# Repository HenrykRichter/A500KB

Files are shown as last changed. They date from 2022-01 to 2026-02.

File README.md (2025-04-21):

# A500KB
This project contains the material related to a custom Commodore Amiga Mechanical Keyboard. While the initial development target was the iconic Amiga 500, the keyboard also fits in A3000/A4000 (maybe also A2000) external keyboard enclosures. It features the ability to mount Mitsumi or Cherry switches. The Power, Drive and Caps-Lock LEDs are implemented as 7 individually configurable RGB LEDs. LED configuration is provided by an AmigaOS program that talks to the Keyboard over the regular connection. Headers for two additional low active input sources (e.g. HDD, Network) are also present.

The keyboard may be populated with two options of Switches and associated Keycaps. The first option are the tactile Mitsumi mechanical switches (E25-33-137) and original A2000/3000/4000 keycaps or A1200.net replica keycaps. Please note that the Mitsumi mechanical switches are quite rare. The second option for switches and keycaps is standard Cherry MX or compatibles. In that latter case, the keycaps for the original Amiga layout are hard to obtain. Recently, the user steveed on [Amibay](https://www.amibay.com/threads/amiga-mx-style-keycaps-pcbs.2446001/) has managed to get replica Amiga compatible keycaps ordered from SignaturePlastics. Consequently, the recent designs of the plate are targeted at Cherry MX compatible stabilizers. The PCB still accepts Mitsumi or Cherry MX (3 pin or 5 pin) compatible switches.

If building the full keyboard is not an option, a sub-project of A500KB might be of interest. The controller part of A500KB is also usable as standalone controller for classic Mitsumi keyboards (A500KB Mini). While that A500KB Mini approach won't give the benefit of mechanical switches, it'll offer the custom LED functionality of A500KB.

Please have a look at the README.md in PCB/ for ordering/building notes.

## Requirements

- Amiga 500 or A3000/A4000 keyboard case
- Main PCB and Switchplate PCB
- 96 Keyswitches (Mitsumi or Cherry)
- parts (including AT90USB1287, IS32FL3237, diodes, LEDs and passives)
- suitable LEDs need to be of ARGB type (analog, common anode) such as Würth 150141M173100, Brightek QBLP677-RGB or similar
- 3D Printed parts for LED light guides (transparent) and spacers

## Pictures

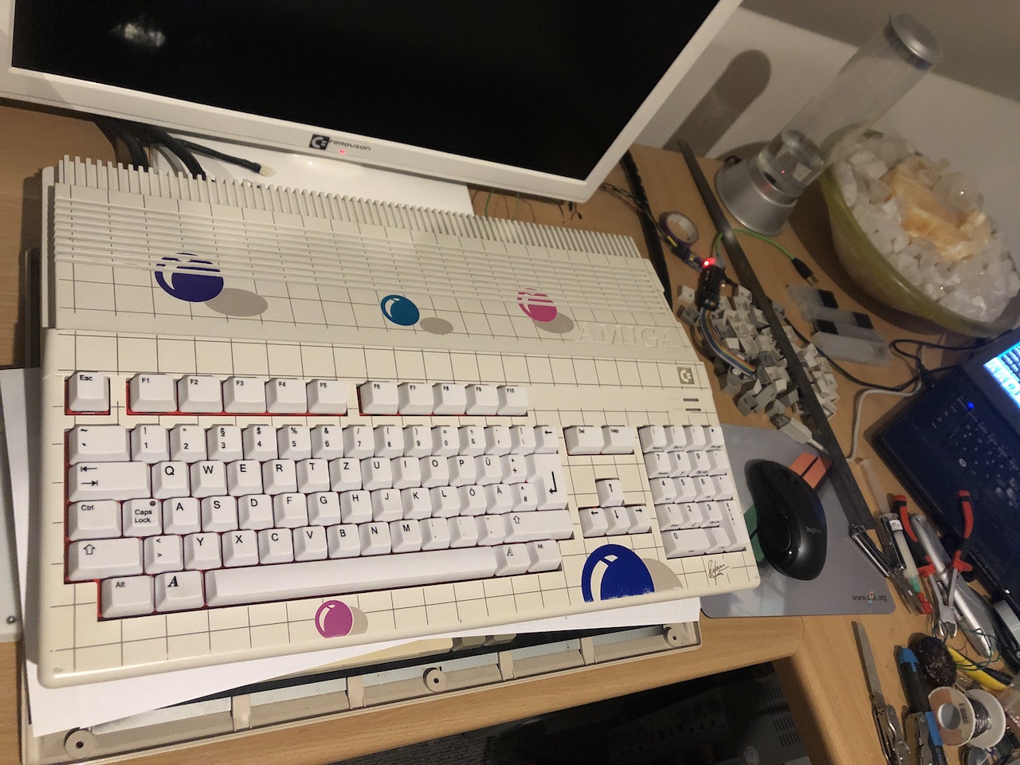
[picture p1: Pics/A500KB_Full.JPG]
front view


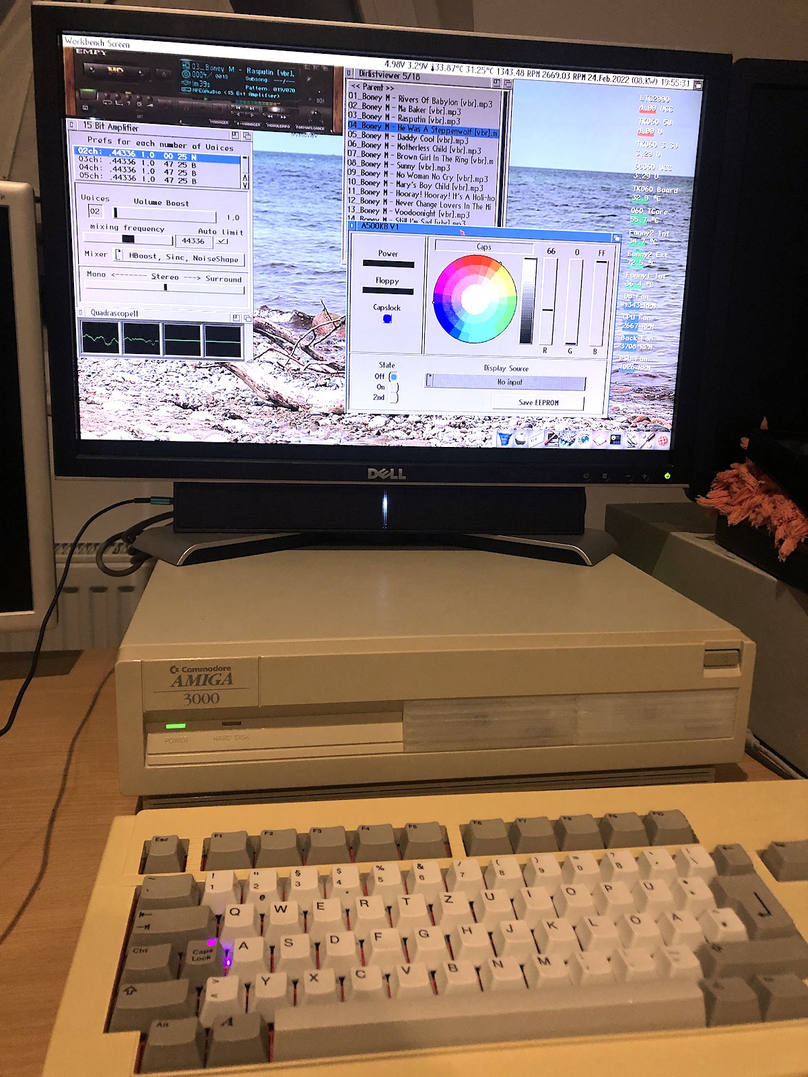
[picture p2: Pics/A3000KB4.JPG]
A3000


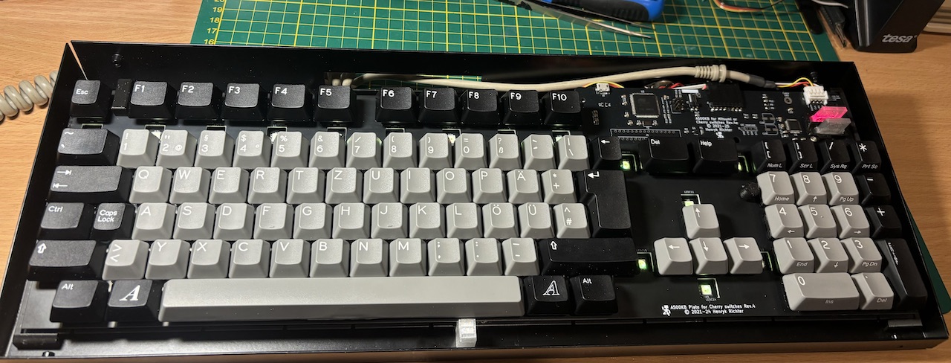
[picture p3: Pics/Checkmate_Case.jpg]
CheckmateCase


## Acknowledgements

Kicad 3D Models and original Footprints imported from:
https://github.com/perigoso/keyswitch-kicad-library

## History

Version 2 of the PCBs addresses several small issues with the prototype. Better fitment is provided for Costar style suports of the larger keys (Shift,Return,Space,Tab etc.). Also, those keys are rotated 90 degrees such that the wire of the supports gets better clearance. The plate PCB got positioning holes for the pins in the top cover of A3000/A4000 keyboards.  Some minor additions were done to the electronics, including larger Diodes and more pullup/down resistors. Version 4 (see below) addresses potential space issues with A500 cases and cabling headers.

A set of 3D printed parts to fit A500KB into the Checkmate external keyboard case has been added in Apr-2025. Please see [3DPrint](https://github.com/HenrykRichter/A500KB/tree/main/3DPrint/Checkmate_KB_Case) for STL files and guidance pictures.

## Caveats

Potential space issues in different styles of A500 cases affected early versions (up to V3) of the design, where the keyboard could only mounted with soldered cables in most A500 cases. Since V4e of the PCB design, the connector J4 has been moved so that it may be populated with an angled pin header and fit all A500 cases as well as external (A2000,A3000,A4000) cases.

## License
The PCB, it's design files and all support code (Amiga, Atmega) are licensed as [CC BY NC SA](https://creativecommons.org/licenses/by-nc-sa/4.0/deed.en).

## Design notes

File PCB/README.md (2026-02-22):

# A500KB Building Notes
This project contains the material related to a custom Commodore Amiga Mechanical Keyboard. While the initial development target was the iconic Amiga 500, the keyboard also fits in A3000/A4000 (maybe also A2000) external keyboard enclosures. It features the ability to mount Mitsumi or Cherry switches. The Power, Drive and Caps-Lock LEDs are implemented as 7 individually configurable RGB LEDs. LED configuration is provided by an AmigaOS program that talks to the Keyboard over the regular connection. Headers for two additional low active input sources (e.g. HDD, Network) are also present.

The two variants of the PCBs in this repository are discussed below. In a nutshell: order PCB and plate for the full keyboard or just the A500KBMini PCB for the standalone controller.

## A500KB (full)

### PCB ordering

**Caution** There are two styles of Keyboard and Plate designs. The one with the suffix "US" is designed specifically for large left Shift (2.75U) and the "BigAss" mirrored L style return key. Should your keycap set include an ISO-style return key (like in most of my pictures), please choose the variant without "US" suffix. See below for comparison pictures towards Keycap styles, if still unsure.

- 1 PCB from A500KB\_Gerber, 2 layer PCB in FR4, 1.2mm thickness for a little more space in bottom case (standard 1.6mm will still be compatible)
- 1 PCB from A500KBPlate\_Gerber, 1 layer PCB in FR4 or Alu, 1mm thickness for PCB or plate mounted MX stabilizers _OR_ A500KBPlate\_Gerber\_V2D.zip for Costar style stabilizers

Starting with V5, there is also a US version of PCB and Plate designs. The US variant includes a large LShift (2.75U) and a large Return (inverted L). Please note that the respective keycaps for ISO Keyboards will not fit on the US version and vice versa.

### 3D printing

The 3D printed parts are in the 3DPrint/ subfolder. Which of those files are to be printed depends on the target enclosure. Please note that bolts and nuts are required for mounting. 
The keyboard framing spacers are designed for countersunk M2.5 bolts with a total length of 5mm. 
The LED frame is to be mounted by flathead M2 bolts with a total length of 5mm and matching nuts.

As of A500KB V4, the 3D printed parts have been unified. The side spacers will fit A500 (and reproduction cases), as well as at least most of the external keyboard cases (tested: A2000,A3000,A4000 Mitsumi cases).

Four parts are designed for all keyboard types: 
- Keyboard\_Spacer\_L\_F2025  - left side of keyboard
- Keyboard\_Spacer\_R\_F2025  - right side of keyboard
- Keyboard\_Spacer\_VL\_F2025 - front left below spacebar
- Keyboard\_Spacer\_VR\_F2025 - front right below cursor keys

A500
- Keyboard\_LEDs\_Rahmen - frame for holding the LED lenses
- Keyboard\_LEDs - LED lenses to be printed (twice!) in transparent filament or resin. Keep infill low.

You also might consider to look at Spacebar\_ExtraSprings for Mitsumi mechanical based builds. This part allows to place additional springs under the space bar in the same way that was present with Mitsumi Amiga keyboards. 

Also of relevance for Mitsumi builds is Keyboard\_CapsLockLED to be printed in transparent filament or resin. This light guide is supposed to point towards the clear dot on the CapsLock key from underneath.

One CDTV Keyboard I came across had studs in its lower case which were about 2mm shorter than those of other 
A2000-4000 keyboards I encountered. The A500KB might sit a bit too low in such CDTV keyboard enclosures. Simply place
three 3D printed adapters of CDTVKeyboard\_Stud\_Adapter.stl on the top row studs in that case.

### Parts

- Please see schematics and/or A500KB.csv for the latest list. All needed components were marked active at the last check with common distributors (like Digikey or Mouser).
- The 7 RGB LEDs need to be of RGBA type (i.e. common Anode) and can be mounted as PLCC or with leads.
- Choose between D1 and D69, depending on switches and keycaps. For CherryMX switches (with SMD LED provision), D69 would be a good choice. D1 is better suited for Mitsumi switches and associated keycaps.
- C15/C16 are not needed.
- The 1x31 flat cable connector (J1) is not needed and stays unpopulated
- Screw-In PCB mounted stabilizers are recommended for Cherry MX and compatible
- see below for a description in which cases R6/R10/R11 need to be installed
- an iBOM is provided as PCB/bom/ibom.html as soldering aid. Please download before use.

### Building

- Solder the SMD components first. 
- Populate either D1 or D69 for CapsLock LED, not both. D2 as classic CapsLock LED is optional. D2 can also be disabled in firmware, if desired (i.e. populate R10 to disable D2).
- Install R6 with 390R for use of RGB LEDs at the positions of Power LED and Floppy LED. Leave R6 open when placing classic Commodore A500 Green/Orange or Red/Green LEDs.
- V3b/V4: install R11 when digital LEDs (SK9822 or APA102) are mounted to D70-D84. Leave R11 open, otherwise

After placing the SMD components, flash the ATMega firmware and verify that the keyboard PCB works.
- Option A) connect by USB to some PC and shorten the pins of the individual keys
- Option B) add A500 cable to J4 and test with AmigaTestKit or similar

Please note that diode reworking after the plate was placed and keyswitches were soldered is not a job I'd look forward to. Therefore, diode soldering and orientation should be verified before going further (!)

For CherryMX based builds, place the PCB mounted stabilizers including their wires in the next step. Screw-In type stabilizers should be preferred. 8U stabilizer wires are not commonly available. Hence, it might be necessary to custom-bend the spacebar wire (133.4mm wide, 1.5-1.6mm diameter).

Afterwards, the keyswitches may be added. It is suggested to place four keyswitches in the corners and one in the middle at first. This tends to help aligning the plate over the main PCB. 

Add the 3D printed spacers, LED frame and lenses.

Consider some electric short protection as the last step after fitment tests are done and possibly remaining THT parts (like J5) are in. For me, two layers of Kapton (or generic Polyimide) tape have been working well. The Kapton doesn't add significant thickness to the main PCB.

### PCB / Plate variant choice

The following pictures should help to decide which PCB and Plate variant to obtain. The critical part in this choice is the Return key, where the mounting points differ significantly between the international version (ISO) version and the US (ANSI) layout.
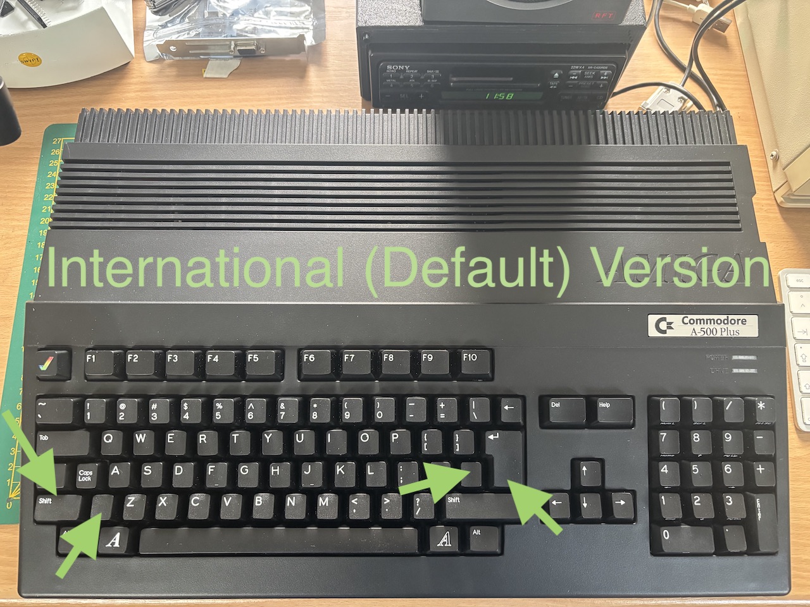
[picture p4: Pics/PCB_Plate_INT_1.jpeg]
INTL

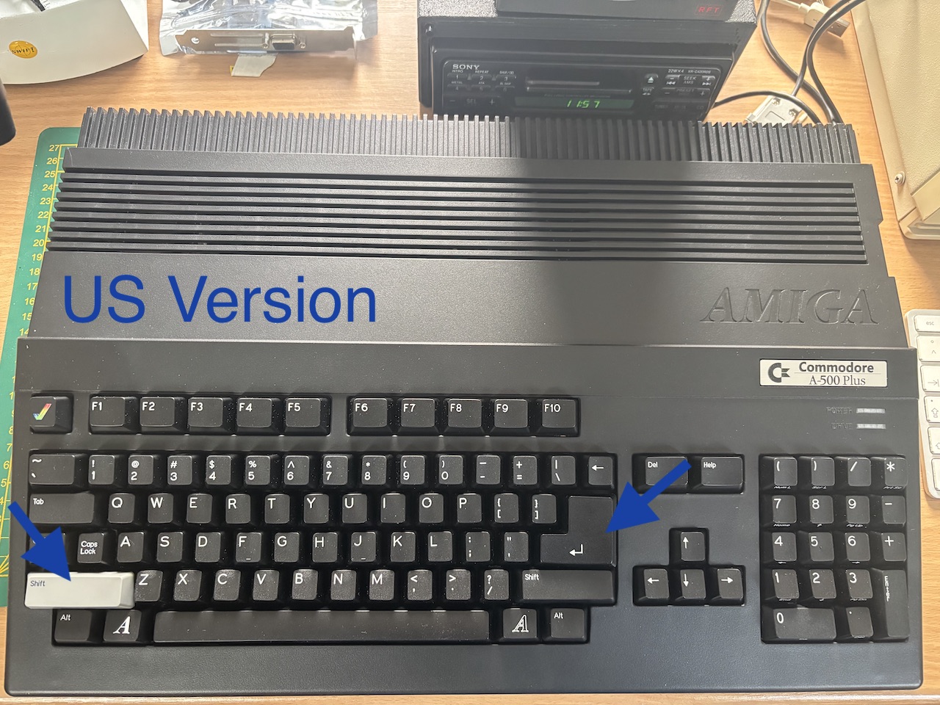
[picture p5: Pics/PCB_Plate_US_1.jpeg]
US1

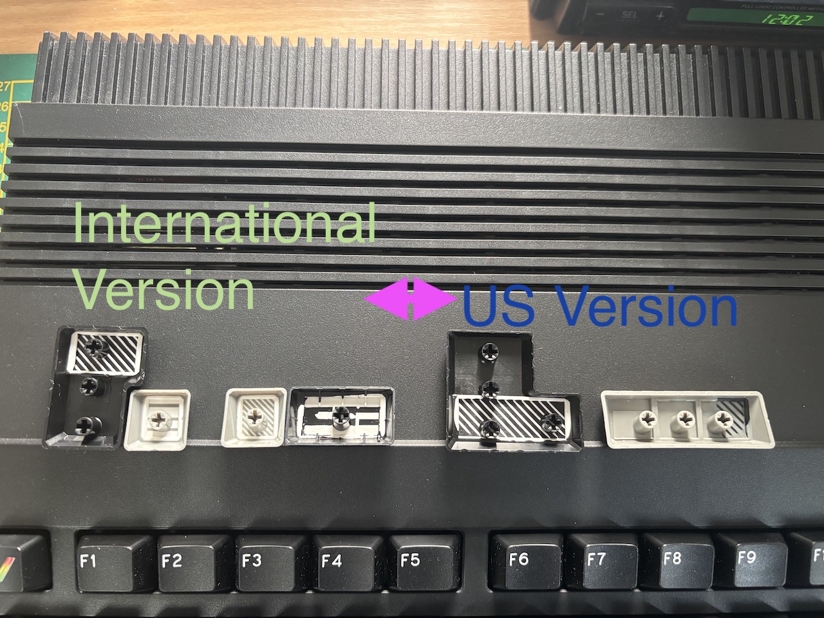
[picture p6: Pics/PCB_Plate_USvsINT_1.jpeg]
CMP1

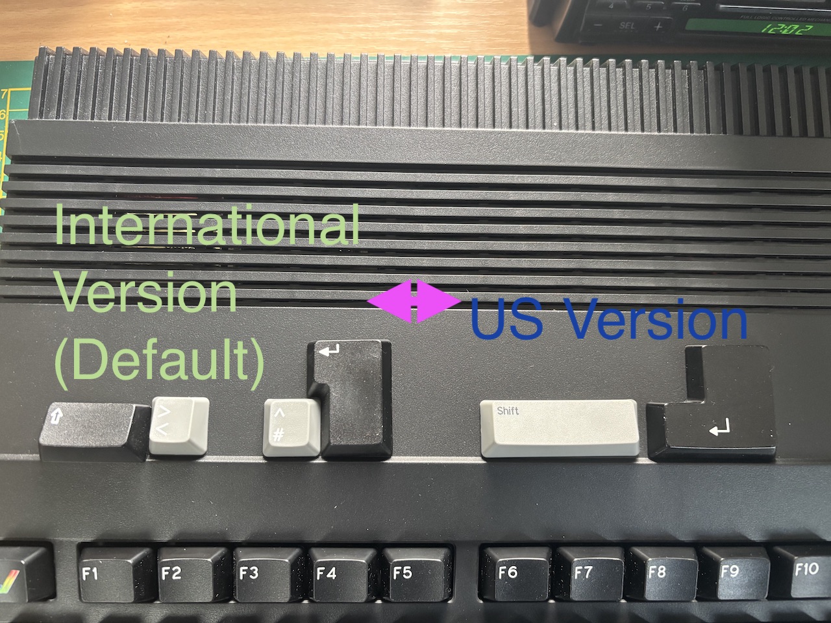
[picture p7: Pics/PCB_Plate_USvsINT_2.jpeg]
CMP2


## A500KBMini

A500KBMini is a little less demanding in the build procedure. There is, however a showstopper for prospective builds. None of the shops I am aware of carries the 1x31 angled FFC connector to be required for A500 Mitsumi Keyboards. Scavenging from broken Mitsumi keyboards might be an option.

### PCB ordering

- 1 PCB from A500KBMini\_Gerber, 2 layer PCB in FR4, 1mm-1.6mm thickness 

### 3D Printing
- Keyboard\_LEDs\_Rahmen as frame for holding the LED lenses
- Keyboard\_LEDs LED lenses to be printed (twice!) in transparent filament or resin

### Parts

- Please see schematics and/or A500KB.csv for the latest list. Exclude the 58 Diodes used for NKRO on the full keyboard. Except from the FFC connector, all other needed components were marked active at the last check with common distributors (like Digikey or Mouser).
- The 6 RGB LEDs need to be of RGBA type (i.e. common anode) and can be mounted as PLCC or with leads.
- C15/C16 are not needed.
- The 1x31 flat cable connector (J1) needs to be obtained and fitted.
- R10/R11 stay unpopulated

### Building

- Solder the SMD components first. 
- Install R6 with 390R for use of RGB LEDs at the positions of Power LED and Floppy LED. Leave R6 open when placing classic A500 Green/Orange or Red/Green LEDs.

After placing the SMD components, flash the ATMega firmware and verify that the keyboard PCB works.

Add the 3D printed LED frame and lenses.

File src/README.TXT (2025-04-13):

-------------------------------------------------------------------------------
- Amiga keyboard controller                                                   -
- author: Henryk Richter <henryk.richter@gmx.net>                             -
-------------------------------------------------------------------------------

This is the AT90USB program for a custom Amiga keyboard I was building. The
keyboard matrix matches the Mitsumi layout. It is active low. Therefore, the 
6 outputs are on by default and pulled down one-by-one in the scanning process. 

Since V4 of the firmware, the USB port has been enabled in device mode. 
CAUTION: USE ONLY ONE CONNECTION, EITHER USB OR AMIGA. NEVER BOTH AT THE SAME 
         TIME. DON'T SAY YOU'VE NOT BEEN WARNED.

The keyboard will act as a Boot mode USB HID device. Please note the following 
caveats: The "#" key (on German keyboards) and the "\" key will emit different 
scan codes (0x31,0x32) result in the same response ("#") with default keyboard 
layouts on PCs/Macs. The keypad [ and ] keys are transmitted as NumLock and 
ScrollLock (as suggested by the secondary label on the keys). CapsLock,NumLock 
and ScrollLock are reflected by the 3 LEDs of the regular floppy row.

---
The flashing of the AT90USB1287 is supposed to be done by an external programmer.
An affordable USBASP clone or some FTDI GPIO wiring would be sufficient to serve
that purpose. The pinout of the 6 pin header is the common Atmel ISP.

Three firmwares A500Mini.hex,A500.hex and A3000.hex are present in this folder
(up to version 3). In V4, the firmware A500A3000Uni.hex was added that will
auto-detect the connection type at runtime and reports "A500" or "A3000",
respectively. Please note that R17 is required on the PCB. 
All of them are functionally identical and just carry different IDs that will
be reflected in the Amiga configuration software.

Example flash procedure (here using USBASP):

avrdude -c usbasp -p at90usb1287 -U flash:w:A500.hex:i
avrdude -c usbasp -p at90usb1287 -U hfuse:w:0x91:m -U lfuse:w:0xdf:m

---
Debugging of the ATMega program:

I've included UART output for debugging purposes. Due to initial design decisions,
there are some caveats to the debugging process. Debug can be enabled by uncommenting
the following line in the Makefile:
DEFS       = -DDEBUG

Please note that the uart outputs are for testing and therefore print only approximate
labels you find on the keys. Also, the UART is connected to KBCLOCK and KBDATA lines.
With debug on, please connect the FT232RL to KBCLOCK/KBDATA and use IN3/IN4 for Amiga
communicationi (Clock/Data, 9k6 8N1).

Consequently, IN3/IN4 inputs are not available while debugging. 

Debugging connection overview:
Amiga:   IN3 = KBCLOCK, IN4 = KBData, remaining pins as usual
FT232RL: KBCLK=RX->FT232TX, KBDATA=TX->FT232RX

Without debug (default builds)
just connect the keyboard in the same way as classic keyboards
--

--
Software version tags:
Beginning with V5, the presence of the LED strip is included
in the version (Bit0). Therefore, versions come in pairs now.
The indicator for LED strip presence is R11. If populated,
then the strip is assumed to be present.

9/10= clock back to 16 MHz, some code optimization
7/8 = watchdog added, reduced clock to 8 MHz, reduced digital LED brightness 
      in order to keep power consumption in check
5/6 = support for LED strip added to the firmware
4 = USB mode added to firmware 
3 = Added A500KB Mini to build variants
2 = Supports (slowly) animated LED modes
1 = initial Release

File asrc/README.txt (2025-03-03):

Short:        Configuration tool for A500KB
Author:       Henryk Richter
Uploader:     henryk.richter@gmx.net (Henryk Richter)
Type:         util/misc
Version:      1.9
Architecture: m68k-amigaos >= 3.0.0
Distribution: NoCD

 Introduction
 ------------

 This is the Amiga-side configuration utility for A500KB
 (https://github.com/HenrykRichter/A500KB) and A500KBMini.

 A500KB is a replacement keyboard for Amiga computers, based
 on mechanical switches. A500KBMini is a simplified spin-off
 project that just replaces the keyboard controller on A500
 Mitsumi keyboards instead of the whole keyboard assembly.

 Features
 --------

 Please refer to the project site (see above) for the keyboard
 capabilities. This utility allows to change brightness, colors
 and actions for any of the 7 RGB LEDs that are mounted
 on A500KB. Any LED may get it's individual idle, primary 
 and secondary colors. Furthermore, the relationship between 
 LED and indicator type is no longer fixed so that you could 
 assign any input source to any LED at up to two indicated
 sources per LED.

 Installation
 ------------
 
 No special installation procedure is required. Just copy it
 to a convenient place on HDD or Floppy.

 Make sure, you have at least AmigaOS3.0. This program makes
 use of the color pen feature that was introduced with 
 Kickstart 3.0. Also needed are the Colorwheel.gadget and
 Gradientslider.gadget in SYS:Classes/Gadgets.

 Invocation
 ----------

 The tool can be started from Workbench, as usual. In case
 of problems at this stage, please verify that the permissions
 are correct (i.e. from CLI: protect A500KBConfig RWED).

 When starting, the tool will try to read the current
 configuration from the A500KB Keyboard. The process usually 
 takes 2-5 seconds. After the config is loaded, the title
 bar of the window will show the keyboard type (by installed
 firmware) and firmware version.

 Depending on the number of available pens (free colors), 
 the tool will open an own Screen. Should the Workbench have
 enough free pens, then the tool opens there.

 Concept and Usage
 -----------------
 
 Click on one of the LEDs in the upper left portion of the
 window to change it's parameters. Please note that the
 Floppy and Power LEDs are segmented into three individual
 LEDs that can be configured as desired.

 In the lower left section of the window is the radio button
 for the LED states. Those three states are:

 Off - LED is idle without active indicator signal
       (typically black or darker for the PowerLED)
 On  - primary Source for which one of the sources
       from the "Display Source" cycle may be selected
 2nd - secondary Source for which one of the sources
       from the "Display Source" cycle may be selected

 If both primary and secondary source are active, then
 the color for the primary source is shown. 

 This way of specifying colors can be used for several
 effects, like inverted operation where the "Off" mode
 could be set for a bright color and the "On"/"2nd" 
 states show darker colors.

 Any change to colors and sources will be applied directly
 in the keyboard, however with a small delay.

 Please note that the changes are non permanent (active
 throughout the current power cycle), until "Save EEPROM" 
 is clicked. 

 There are two menu options "Load Preset" and "Save Preset"
 that can be used to load/save a full color scheme.

 History
 -------

 1.9 - added abiity to switch between BRG and BGR
       for LED strip (SK9822 vs. APA102)
     - added presets menu
 1.8 - added support for LED strip on board revision
       3b (and 4) including base color and effect
       control
 1.7 - added optional color changing modes to LEDs

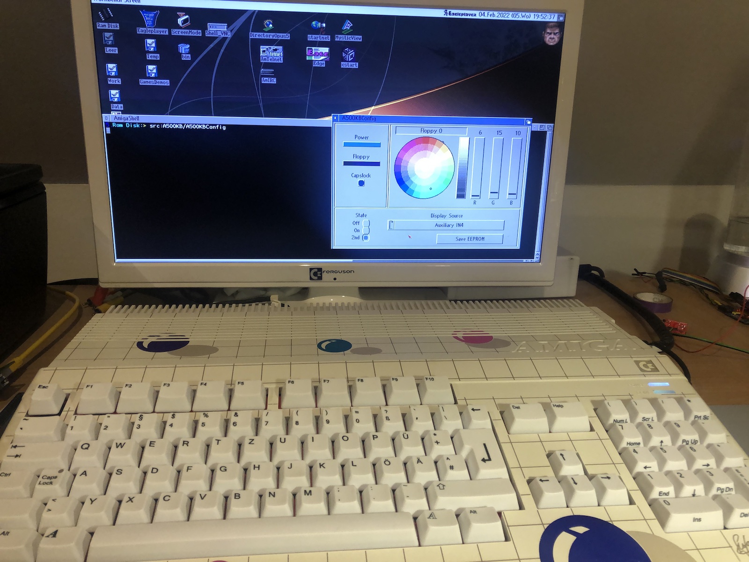
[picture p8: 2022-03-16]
Pics/Done_Overview.JPG

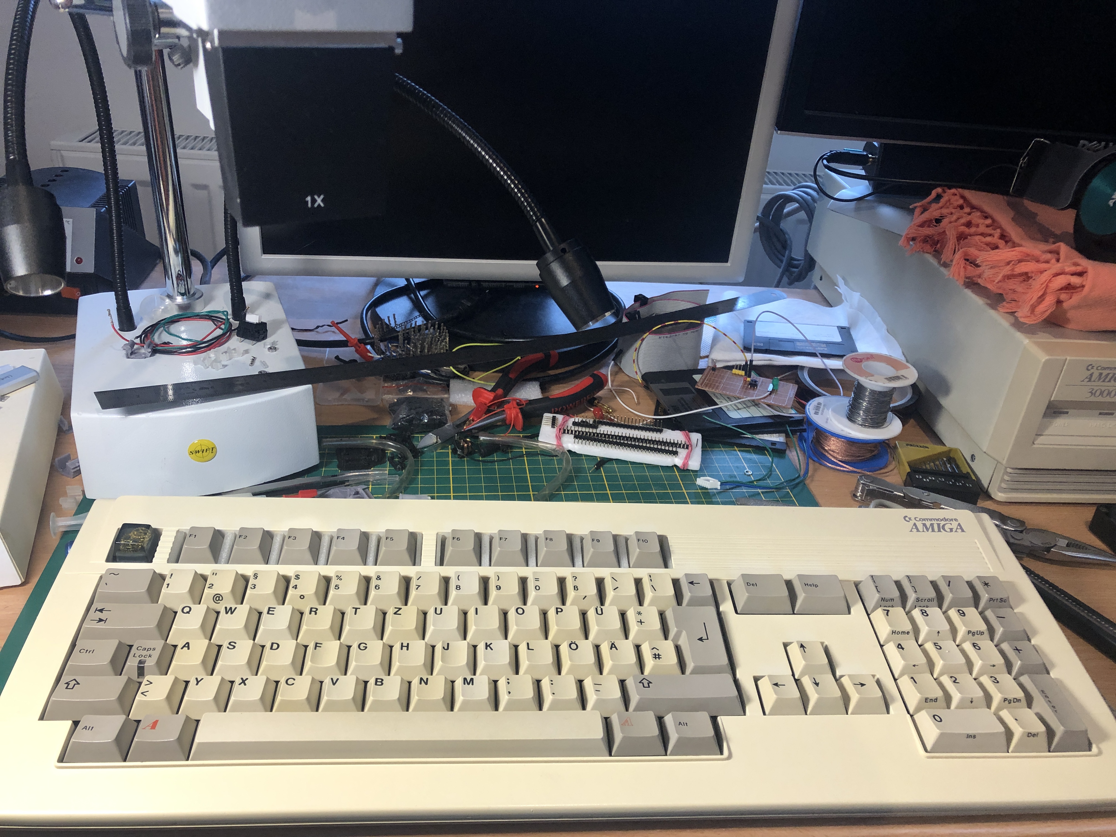
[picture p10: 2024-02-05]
Pics/CherryKB4.JPG

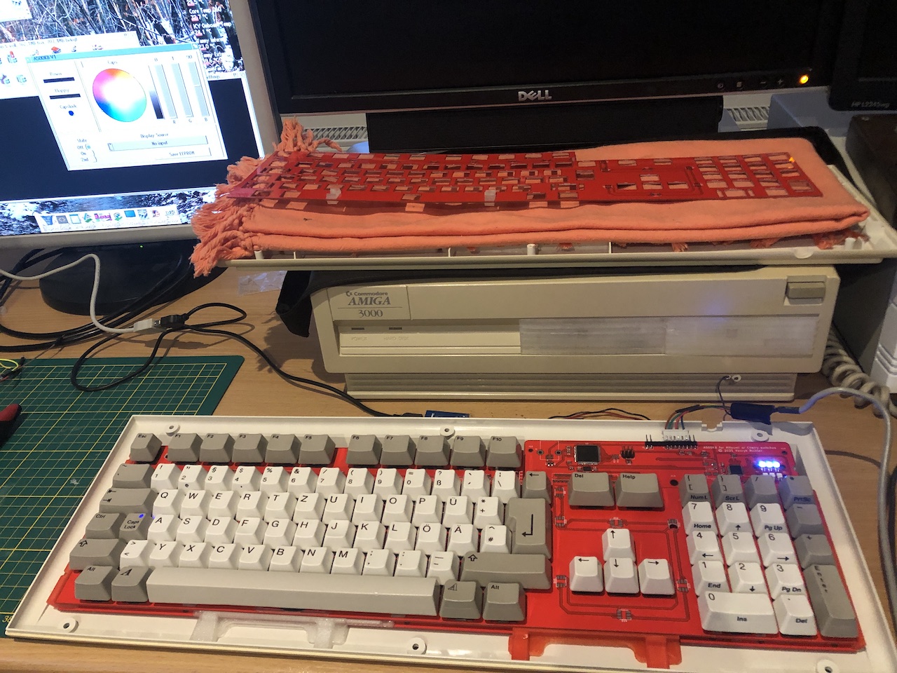
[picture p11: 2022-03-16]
Pics/A4000_2.JPG

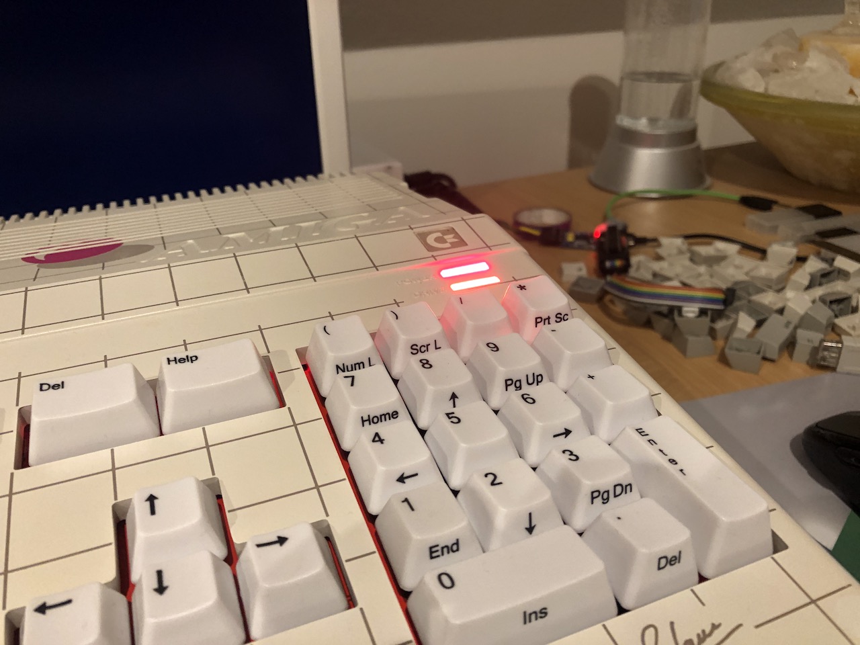
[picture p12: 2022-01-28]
Pics/A500KB_LEDs.JPG

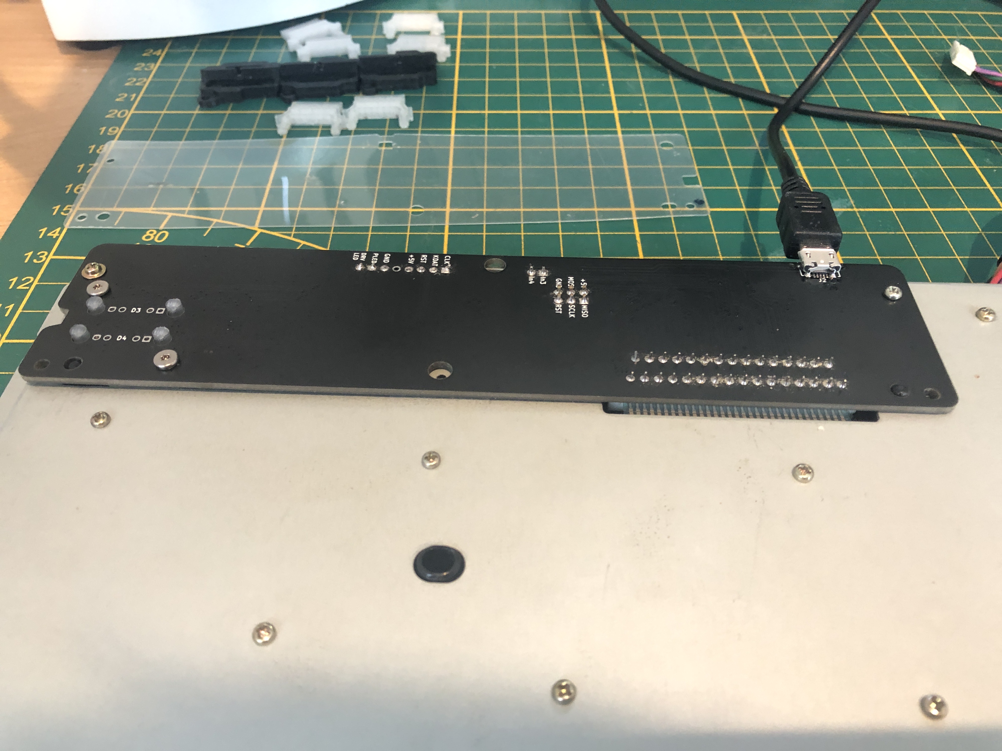
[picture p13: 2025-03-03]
Pics/A500KBMini_USB_Micro.JPG

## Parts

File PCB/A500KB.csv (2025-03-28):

Id | Designator | Footprint | Quantity | Designation | Supplier and ref
1 | MX1 | MXMitsumi-1U-NoLED | 1 | ESC
2 | MX2 | MXMitsumi-1.5U-NoLED | 1 | tilde
3 | MX4 | MXMitsumi-1.25U-NoLED | 1 | CTRL
4 | MX5 | MXMitsumi-1.75U-NoLED | 1 | LShift
5 | MX6 | MXMitsumi-1.25U-NoLED | 1 | Lalt
6 | MX8 | MXMitsumi-1U-NoLED | 1 | 1
7 | MX10 | MXMitsumi-1U-NoLED | 1 | CAPS
8 | MX11 | MXMitsumi-1U-NoLED | 1 | <>
9 | MX12 | MXMitsumi-1.25U-NoLED | 1 | Lamiga
10 | MX13 | MXMitsumi-1.25U-NoLED | 1 | F2
11 | MX14 | MXMitsumi-1U-NoLED | 1 | 2
12 | MX16 | MXMitsumi-1U-NoLED | 1 | A
13 | MX17 | MXMitsumi-1U-NoLED | 1 | Z
14 | MX18 | MXMitsumi-1.25U-NoLED | 1 | F3
15 | MX19 | MXMitsumi-1U-NoLED | 1 | 3
16 | MX20 | MXMitsumi-1U-NoLED | 1 | E
17 | MX21 | MXMitsumi-1U-NoLED | 1 | S
18 | MX22 | MXMitsumi-1U-NoLED | 1 | X
19 | MX23 | MXMitsumi-1.25U-NoLED | 1 | F4
20 | MX24 | MXMitsumi-1U-NoLED | 1 | 4
21 | MX25 | MXMitsumi-1U-NoLED | 1 | R
22 | MX26 | MXMitsumi-1U-NoLED | 1 | D
23 | MX27 | MXMitsumi-1U-NoLED | 1 | C
24 | MX28 | MXMitsumi-1.25U-NoLED | 1 | F5
25 | MX30 | MXMitsumi-1U-NoLED | 1 | T
26 | MX32 | MXMitsumi-1U-NoLED | 1 | V
27 | MX34 | MXMitsumi-1.25U-NoLED | 1 | F6
28 | MX35 | MXMitsumi-1U-NoLED | 1 | 6
29 | MX37 | MXMitsumi-1U-NoLED | 1 | G
30 | MX38 | MXMitsumi-1U-NoLED | 1 | B
31 | MX39 | MXMitsumi-1.25U-NoLED | 1 | F7
32 | MX40 | MXMitsumi-1U-NoLED | 1 | 7
33 | MX41 | MXMitsumi-1U-NoLED | 1 | U
34 | MX42 | MXMitsumi-1U-NoLED | 1 | H
35 | MX43 | MXMitsumi-1U-NoLED | 1 | N
36 | MX45 | MXMitsumi-1U-NoLED | 1 | 8
37 | MX46 | MXMitsumi-1U-NoLED | 1 | I
38 | MX47 | MXMitsumi-1U-NoLED | 1 | J
39 | MX49 | MXMitsumi-1.25U-NoLED | 1 | F9
40 | MX50 | MXMitsumi-1U-NoLED | 1 | 9
41 | MX51 | MXMitsumi-1U-NoLED | 1 | O
42 | MX52 | MXMitsumi-1U-NoLED | 1 | K
43 | MX53 | MXMitsumi-1U-NoLED | 1 | ,
44 | MX54 | MXMitsumi-1.25U-NoLED | 1 | F10
45 | MX55 | MXMitsumi-1U-NoLED | 1 | 0
46 | MX56 | MXMitsumi-1U-NoLED | 1 | P
47 | MX57 | MXMitsumi-1U-NoLED | 1 | L
48 | MX58 | MXMitsumi-1U-NoLED | 1 | .
49 | MX59 | MXMitsumi-1.25U-NoLED | 1 | Ramiga
50 | MX60 | MXMitsumi-1U-NoLED | 1 | -
51 | MX61 | MXMitsumi-1U-NoLED | 1 | [{
52 | MX62 | MXMitsumi-1U-NoLED | 1 | COLON
53 | MX63 | MXMitsumi-1U-NoLED | 1 | Question
54 | MX64 | MXMitsumi-1.25U-NoLED | 1 | Ralt
55 | MX65 | MXMitsumi-1U-NoLED | 1 | +
56 | MX67 | MXMitsumi-1U-NoLED | 1 | ";;; 57;MX68" | MXMitsumi-2.75U-NoLED | 1 | RShift
58 | MX69 | MXMitsumi-1U-NoLED | 1 | \
59 | MX70 | MXMitsumi-1U-NoLED | 1 | #
60 | MX71 | MXMitsumi-ISO-NoLED | 1 | Return
61 | MX72 | MXMitsumi-1U-NoLED | 1 | BkSpace
62 | MX73 | MXMitsumi-1.5U-NoLED | 1 | DEL
63 | MX74 | MXMitsumi-1U-NoLED | 1 | left
64 | MX75 | MXMitsumi-1U-NoLED | 1 | up
65 | MX76 | MXMitsumi-1U-NoLED | 1 | down
66 | MX77 | MXMitsumi-1.5U-NoLED | 1 | HELP
67 | MX78 | MXMitsumi-1U-NoLED | 1 | right
68 | MX79 | MXMitsumi-1U-NoLED | 1 | NUM_(
69 | MX80 | MXMitsumi-1U-NoLED | 1 | NUM_7
70 | MX81 | MXMitsumi-1U-NoLED | 1 | NUM_4
71 | MX82 | MXMitsumi-1U-NoLED | 1 | NUM_1
72 | MX83 | MXMitsumi-2U-NoLED | 1 | NUM_0
73 | MX85 | MXMitsumi-1U-NoLED | 1 | NUM_8
74 | MX86 | MXMitsumi-1U-NoLED | 1 | NUM_5
75 | MX87 | MXMitsumi-1U-NoLED | 1 | NUM_2
76 | MX88 | MXMitsumi-1U-NoLED | 1 | NUM_/
77 | MX89 | MXMitsumi-1U-NoLED | 1 | NUM_9
78 | MX90 | MXMitsumi-1U-NoLED | 1 | NUM_6
79 | MX91 | MXMitsumi-1U-NoLED | 1 | NUM_3
80 | MX92 | MXMitsumi-1U-NoLED | 1 | NUM_.
81 | MX93 | MXMitsumi-1U-NoLED | 1 | NUM_*
82 | MX94 | MXMitsumi-1U-NoLED | 1 | NUM_-
83 | MX95 | MXMitsumi-1U-NoLED | 1 | NUM_+
84 | MX96 | MXMitsumi-2U-VerticalStabilizers-NoLED | 1 | NUM_ENTER
85 | MX9 | MXMitsumi-1U-NoLED | 1 | Q
86 | MX15 | MXMitsumi-1U-NoLED | 1 | W
87 | MX7 | MXMitsumi-1.25U-NoLED | 1 | F1
88 | MX3 | MXMitsumi-2U-NoLED | 1 | Tab
89 | MX36 | MXMitsumi-1U-NoLED | 1 | Y
90 | MX31 | MXMitsumi-1U-NoLED | 1 | F
91 | MX29 | MXMitsumi-1U-NoLED | 1 | 5
92 | MX48 | MXMitsumi-1U-NoLED | 1 | M
93 | MX66 | MXMitsumi-1U-NoLED | 1 | ]}
94 | MX84 | MXMitsumi-1U-NoLED | 1 | NUM_)
95 | MX44 | MXMitsumi-1.25U-NoLED | 1 | F8
96 | D2 | D_0805_2012Metric_Pad1.15x1.40mm_HandSolder | 1 | CAPS2
97 | MX33 | MXMitsumi-9U-NoLED | 1 | Space
98 | Q1 | SOT-23 | 1 | MMBT3904
99 | R1,R12 | R_0805_2012Metric_Pad1.20x1.40mm_HandSolder | 2 | 1k
100 | R2 | R_0805_2012Metric_Pad1.20x1.40mm_HandSolder | 1 | 180
101 | C5 | C_0805_2012Metric_Pad1.18x1.45mm_HandSolder | 1 | 1uF
102 | C6,C13,C9,C2,C7,C8 | C_0805_2012Metric_Pad1.18x1.45mm_HandSolder | 6 | 100nF
103 | J3 | PinHeader_2x03_P2.54mm_Vertical | 1 | Conn_02x03_Odd_Even
104 | R4,R8,R9,R3 | R_0805_2012Metric_Pad1.20x1.40mm_HandSolder | 4 | 22
105 | R5 | R_0805_2012Metric_Pad1.20x1.40mm_HandSolder | 1 | 4.7k
106 | U2 | TQFP-64_14x14mm_P0.8mm | 1 | AT90USB1287-A
107 | Y2 | Crystal_SMD_TXC_7A-2Pin_5x3.2mm | 1 | 16 MHz
108 | J4 | PinHeader_1x08_P2.54mm_Horizontal | 1 | Conn_01x08_Male
109 | D1 | LED_Cree-PLCC4_3.2x2.8mm_CCW | 1 | RGBCAPS_MITSUMI
110 | J5 | PinHeader_1x02_P2.54mm_Horizontal | 1 | Conn_01x02
111 | H5,H6,H7,H8,H9,H10,H11,H12,H13,H14,H1,H2,H4,H20,H21,H3 | MountingHole_3.2mm_M3_Small_Bax | 16 | MountingHole
112 | R6 | R_0805_2012Metric_Pad1.20x1.40mm_HandSolder | 1 | 390
113 | C14,C1,C10,C11,C12,C18,C17,C19 | C_0805_2012Metric_Pad1.18x1.45mm_HandSolder | 8 | 10uF
114 | C3,C4 | C_0805_2012Metric_Pad1.18x1.45mm_HandSolder | 2 | 22pF
115 | J1 | FFC-1.25mm-Molex-39-53-2314 | 1 | N/A
116 | H15,H17,H16,H18,H22,H23 | MountingHole_2.5mm | 6 | MountingHole
117 | D8,D9,D10,D11,D12,D13,D14,D15,D16,D17,D18,D19,D20,D21,D22,D24,D25,D26,D27,D28,D29,D30,D31,D32,D33,D34,D35,D36,D37,D38,D39,D40,D41,D42,D43,D44,D45,D46,D47,D48,D49,D50,D54,D55,D56,D57,D58,D59,D60,D61,D62,D63,D64,D65,D66,D67,D68,D23 | D_SOD-123 | 58 | 1N4148W
118 | H19 | MountingHole_4.3mm_M4 | 1 | MountingHole
119 | D5,D6,D7,D52,D53,D51 | LED_Cree-PLCC4_3.2x2.8mm_CCW | 6 | LED_ARBG
120 | U1 | TQFP-48-1EP_7x7mm_P0.5mm_EP5x5mm_ThermalVias | 1 | IS32FL3237_DS
121 | R7 | R_0805_2012Metric_Pad1.20x1.40mm_HandSolder | 1 | 3.9k
122 | R10,R11,R16,R15 | R_0805_2012Metric_Pad1.20x1.40mm_HandSolder | 4 | 10k
123 | R13,R14 | R_0805_2012Metric_Pad1.20x1.40mm_HandSolder | 2 | 3.3k
124 | J2 | USB_Micro-B_Molex-105017-0001 | 1 | USB_B_Micro
125 | J6 | PinHeader_1x04_P2.54mm_Vertical | 1 | N/A
126 | D69 | LED_Cree-PLCC4_3.2x2.8mm_CCW | 1 | RGBCAPS_MX
127 | D72,D73,D83,D71,D70,D81,D80,D77,D75,D78,D76,D79,D84,D74,D82 | LED_RGB_5050-6 | 15 | APA102
128 | R17 | R_0805_2012Metric_Pad1.20x1.40mm_HandSolder | 1 | 150k
129 | H24 | MountingHole_2.5mm_Pad_TopBottom | 1 | MountingHole_Pad
130 | J7 | JST_EH_S4B-EH_1x04_P2.50mm_Horizontal | 1 | Conn_01x04
131 | D3,D4 | LED_DUAL_A500 | 2 | LED_Dual_ACAC

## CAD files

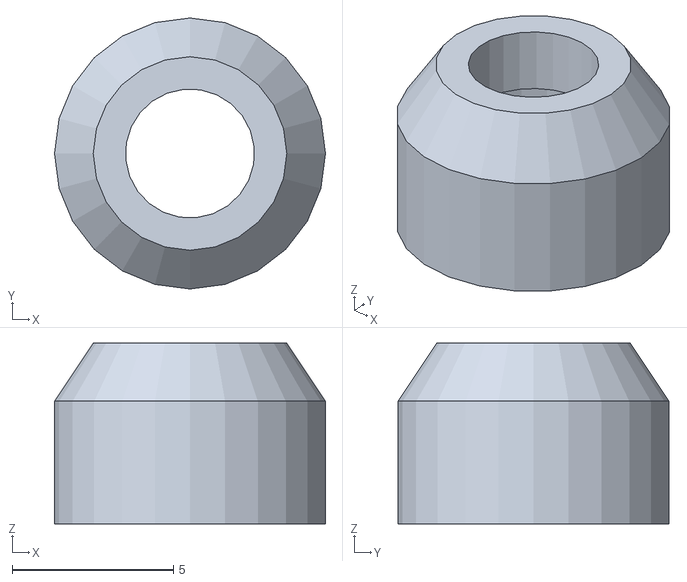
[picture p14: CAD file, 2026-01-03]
3DPrint/CDTVKeyboard_Stud_Adapter.stl
8.40 x 8.40 x 5.60

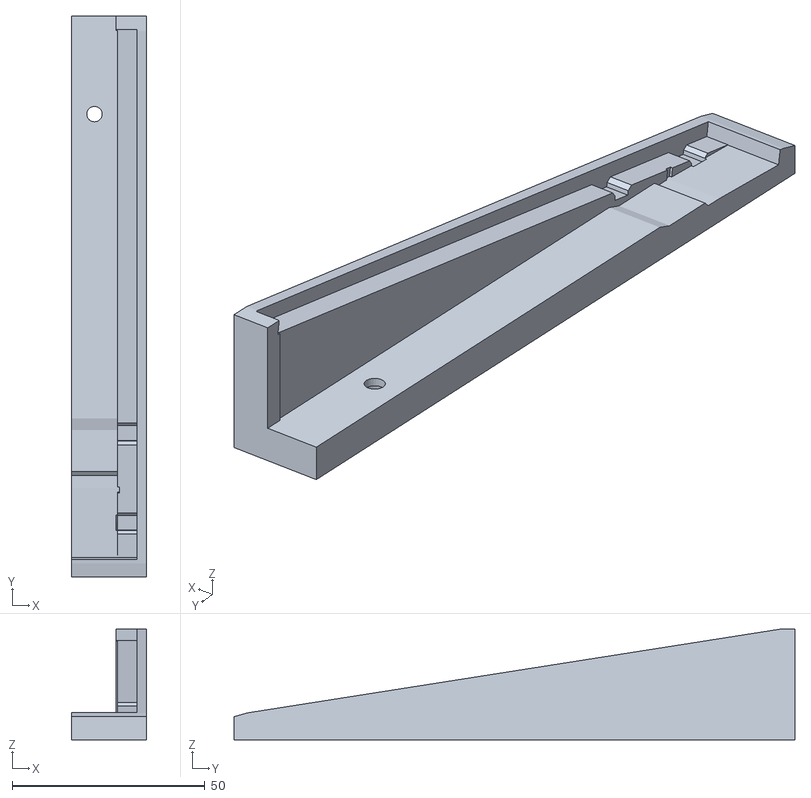
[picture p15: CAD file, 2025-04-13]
3DPrint/Checkmate_KB_Case/CheckMateKBCase_R.stl
19.5 x 145.3 x 28.7

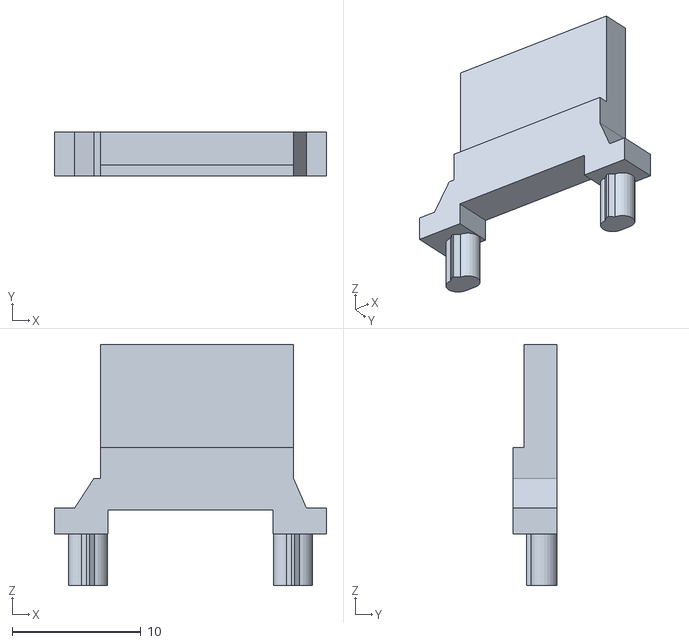
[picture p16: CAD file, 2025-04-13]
3DPrint/Checkmate_KB_Case/Keyboard_LEDs_Checkmate.stl
21.1 x 3.40 x 18.7

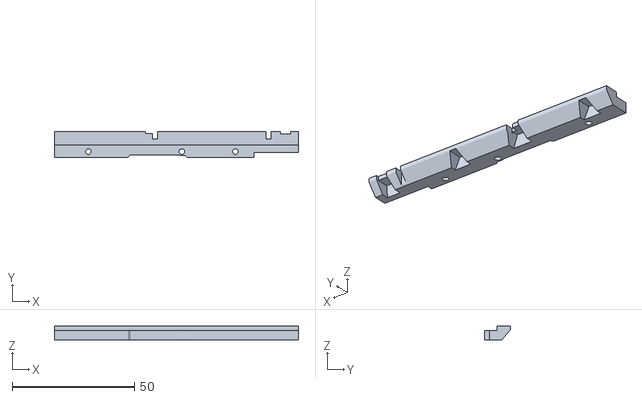
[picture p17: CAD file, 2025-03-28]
3DPrint/Keyboard_Spacer_L_F2025.stl
100.0 x 10.5 x 5.70

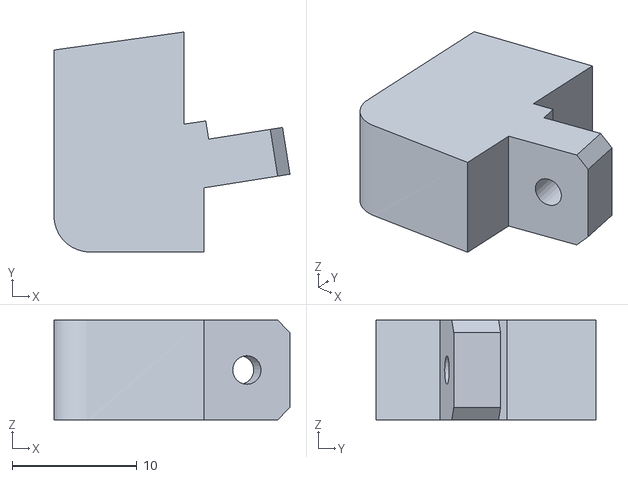
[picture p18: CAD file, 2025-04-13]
3DPrint/Checkmate_KB_Case/Holder_front_under_Spacebar_right.stl
18.9 x 17.6 x 8.00

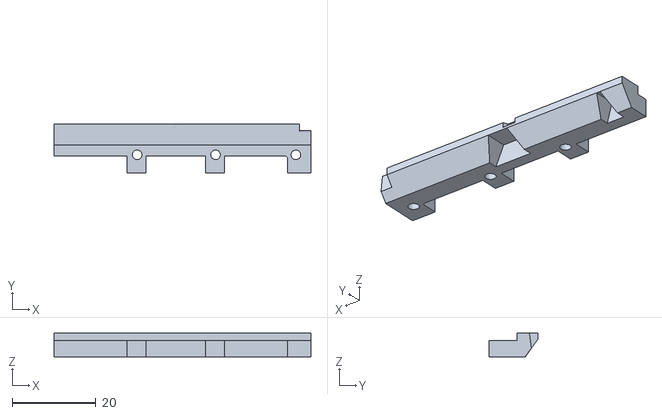
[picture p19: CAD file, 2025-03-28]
3DPrint/Keyboard_Spacer_R_F2025.stl
61.2 x 11.6 x 5.70

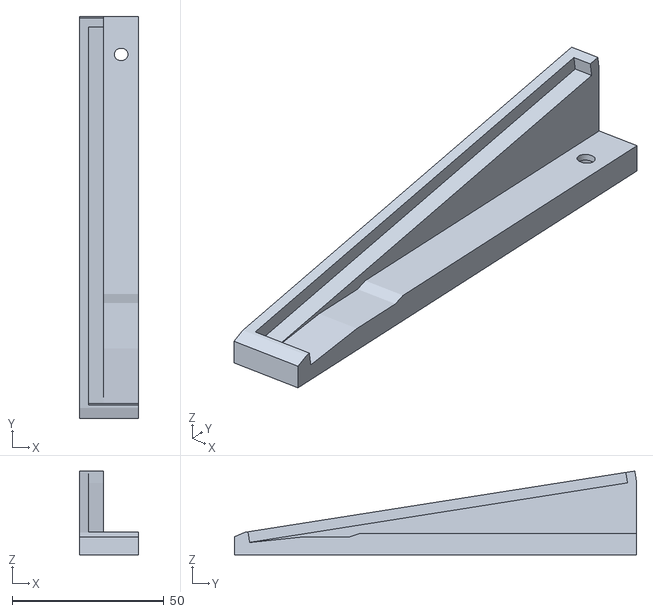
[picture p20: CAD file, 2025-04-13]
3DPrint/Checkmate_KB_Case/CheckMateKBCase_L.stl
19.5 x 132.4 x 27.7

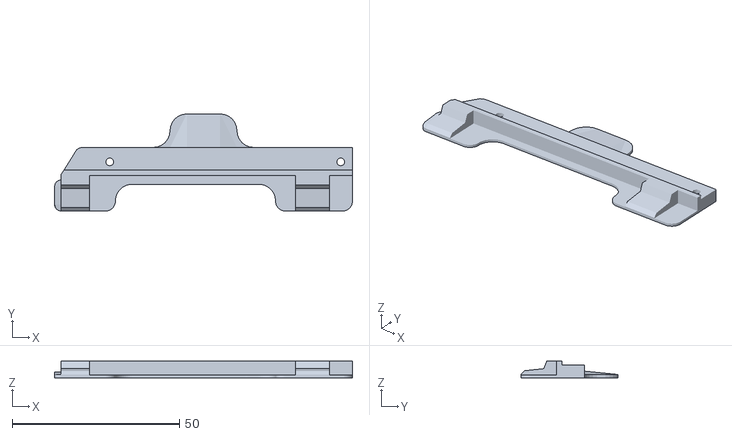
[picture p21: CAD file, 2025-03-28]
3DPrint/Keyboard_Spacer_VR_F2025.stl
89.0 x 29.0 x 5.00

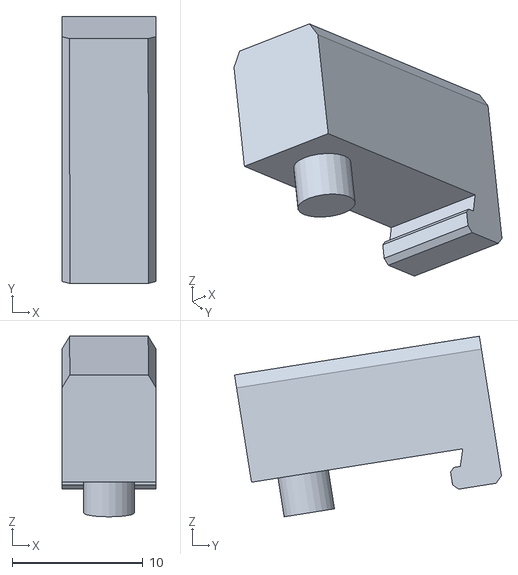
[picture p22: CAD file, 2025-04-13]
3DPrint/Checkmate_KB_Case/CheckMateKBCase_Distknob.stl
7.20 x 20.4 x 13.8

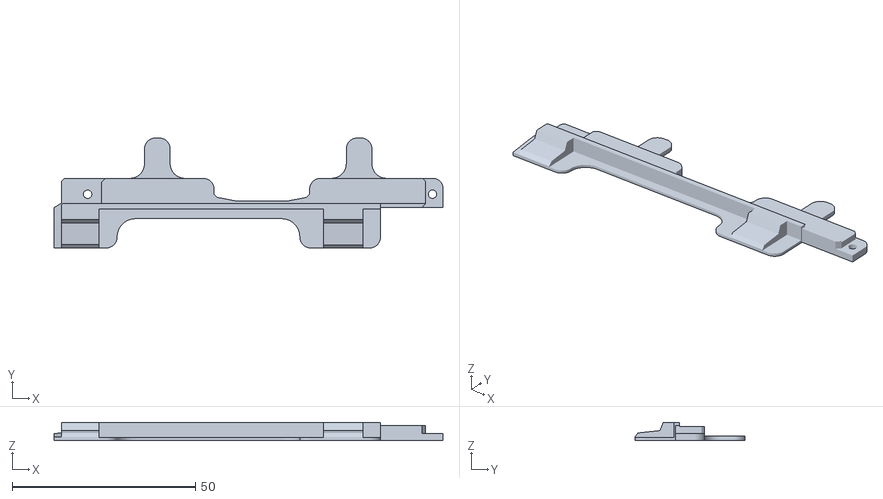
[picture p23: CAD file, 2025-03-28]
3DPrint/Keyboard_Spacer_VL_F2025.stl
106.0 x 30.0 x 5.00

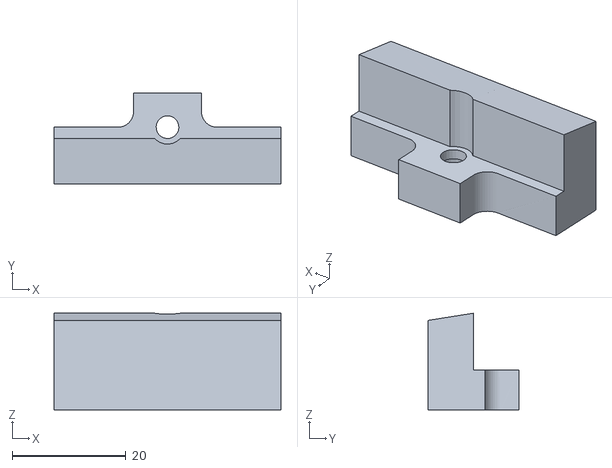
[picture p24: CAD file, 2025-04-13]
3DPrint/Checkmate_KB_Case/CheckMateKBCase_BackHold.stl
40.0 x 16.0 x 17.0

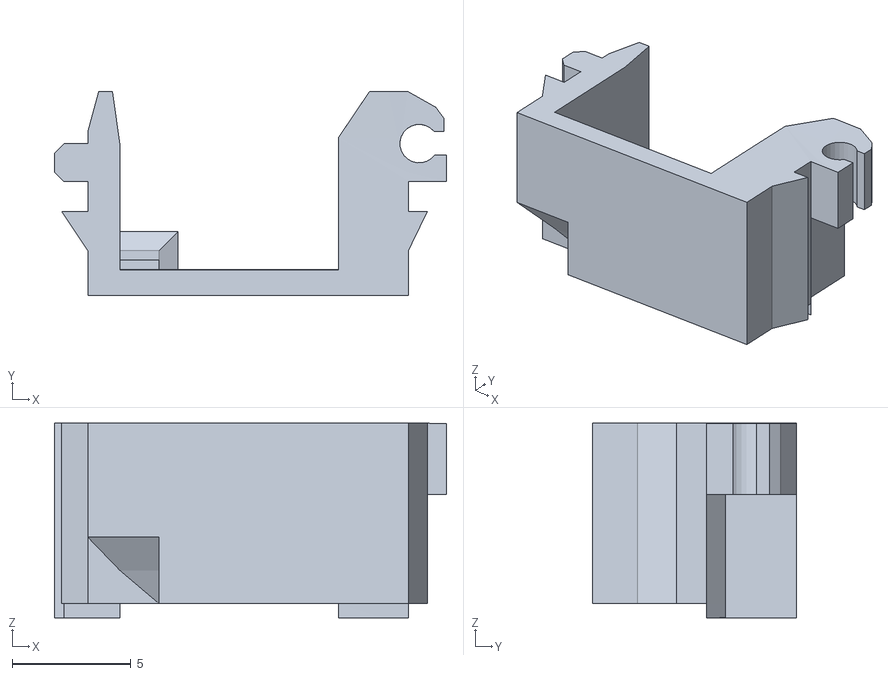
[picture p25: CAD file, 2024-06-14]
3DPrint/Keyboard_Guide_SPCR.stl
16.5 x 8.60 x 8.20

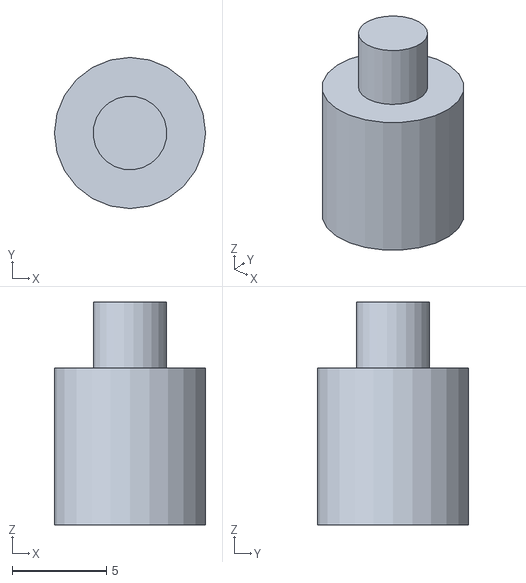
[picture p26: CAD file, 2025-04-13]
3DPrint/Checkmate_KB_Case/CheckMateKBCase_Knob2.stl
8.00 x 8.00 x 11.8

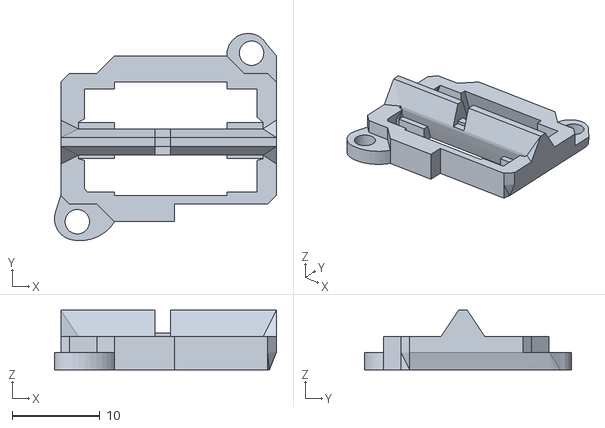
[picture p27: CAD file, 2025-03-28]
3DPrint/Checkmate_KB_Case/Keyboard_LEDs_Frame.stl
25.4 x 23.7 x 6.80

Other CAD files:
3DPrint/Keyboard_Guide_SPCL.stl
3DPrint/Keyboard_LEDs_1.4mm_more.stl
3DPrint/Keyboard_CapsLockLED.stl
3DPrint/Spacebar_ExtraSprings.stl
3DPrint/CDTVKeyboard_Stud_Adapter.skp
3DPrint/Checkmate_KB_Case/CheckMateKBCase_1.skp
3DPrint/Checkmate_KB_Case/Holder_front_under_Spacebar_right.skp
3DPrint/Checkmate_KB_Case/Keyboard_LEDs_Checkmate.skp
3DPrint/Keyboard_CapsLockLED.skp
3DPrint/Keyboard_Guide.skp
3DPrint/Keyboard_Guide.stl
3DPrint/Keyboard_LEDs.skp
3DPrint/Keyboard_Spacer_L_F2025.skp
3DPrint/Keyboard_Spacer_R_F2025.skp
3DPrint/Keyboard_Spacer_VL_F2025.skp
3DPrint/Keyboard_Spacer_VR_F2025.skp
3DPrint/Spacebar_ExtraSprings.skp

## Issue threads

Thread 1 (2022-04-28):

PCB production parameters

kavanozz, 2022-04-28:
I am interested in your projects, looks very good. Can you please provide the preferred parameters used in the production of the PCBs? Probably most important one is the tickness.

HenrykRichter, 2022-07-25:
My apologies for the late answer. I've had the main PCBs built with 1.6mm thickness and the plates with 1mm. As an afterthought, 1.2mm would probably have been better for the plates.

In scenarios where only the main PCB is desired (like for Cherry switches with mounting pin), a higher thickness >= 2mm would be a good choice.

Closed 2022-08-10.

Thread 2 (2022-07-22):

Cherry and KailH switches

jcagigal, 2022-07-22:
Hi! Thanks for sharing this awesome project, could you please let us know which Cherry and KailH switches references could be used? Would it accept different kind of pc keyboard-like keys? Best regards, Jaime.

HenrykRichter, 2022-07-25:
The design is prepared for classic Cherry switches (any color) with or without mounting/centering pin. KailH and Gateron switches have the same outer parameters. I've test-fitted Cherry White and KailH Box-brown.  One of my Keyboards is built using Cherry Blue (clicky) switches and is equipped with keycaps originating from an old A2000 keyboard (which I didn't get alongside the caps).

Right now I haven't tried to obtain a full keyset (keycaps) from aftermarket vendors. The main challenge would be to get 9U space bars. Also, due to different widths of F1-F10, DEL, HELP and others, a non sculptured profile like DCS would be a good start.

Closed 2022-08-10.

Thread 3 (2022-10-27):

RGB led examples

kavanozz, 2022-10-27:
Hi Henryk,

I ordered a few partially assembled PCBs to JLC. I picked this RGB led for D1, 5, 6, 7, 51, 52, 53 but they said it doesn't fit in there.
https://www.lcsc.com/product-detail/Light-Emitting-Diodes-LED_MEIHUA-MHPA3528RGBCT_C409779.html

I will hand solder them. Can you please give some examples from Mouser/Digikey or some other vendor?

For the plate RBG leds (APA102 5050), are these the correct ones?
https://www.sparkfun.com/products/14863

Thanks

HenrykRichter, 2022-10-27:
Yes, the pads were drawn with hand soldering in mind as a middle ground between analog LEDs with leads and PLCC type LEDs. I had Würth LEDs in mind (order# 150141M173100).

Please don't populate the plate when using the assembly in original Amiga 2000/3000/4000 keyboard cases or A500's. The plate will touch the keyboard cover and pinch LEDs mounted there. For that reason, firmware and software support for these extra LEDs was not implemented.

Closed 2022-10-27.

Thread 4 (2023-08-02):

BOM and CPL files and programming/flashing.

gotnull, 2023-08-02:
Would it be possible for you to provide a BOM with MFG Part Numbers and CPL file for the A500?

HenrykRichter, 2023-08-02:
That most probably won't happen on my part, I'm afraid. I've never planned to have my PCBs populated from the factory and consequently didn't look up part numbers at LCSC.

I'd happily add those files to the repository, should somebody go through the process of collecting part numbers.

kavanoz64, 2023-08-02:
I had PCBs produced some time ago with assembly. Due to other projects, I never got to finish it. I'm attaching the files here. I didn't check if the parts are still in the stocks at JLC/LCSC, so you may need to find replacements for some of them. I didn't include U1 and U2 as I intended to hand solder them. Larger leds were also not included.
[BOM-A500KB.csv](https://github.com/HenrykRichter/A500KB/files/12245310/BOM-A500KB.csv)
[POS-A500KB.csv](https://github.com/HenrykRichter/A500KB/files/12245311/POS-A500KB.csv)

gotnull, 2023-08-02:
Appreciate the upload. I’m actually going to attempt to get some produced so I might ping you when I get to the firmware part if that’s okay as I’m not actually sure which wires to hook up the TTL to or what software is required to flash the firmware.

Like I mentioned this will be for a couple of A500’s.

I wasn’t sure whether there were any SMD components that weren’t required for the A500 and they can be skipped in the BOM/CPL.

gotnull, 2023-08-03:
You mention:

> UART is connected to KBCLOCK and KBDATA lines. With debug on, please
connect the FT232RL to KBCLOCK/KBDATA and use IN3/IN4 for Amiga communication.

I can see the CLK and KDATA on the PCB near RST and 5V+ so I'm guessing these are KBCLOCK/KBDATA that you're referring to. What I'm not sure about is "use IN3/IN4 for Amiga communication", what do you mean by that?

Also I have managed to build and compile the `A500KBConfig` program and the `ATmegaBoard.hex` successfully.

gotnull, 2023-08-04:
@HenrykRichter any help with the flashing would be much appreciated.

HenrykRichter, 2023-08-19:
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
Please have a look at the updated repository. I've done some improvements to the A500KBConfig program (now at version 1.7) which address timing issues I encountered on slow Amigas (68000/68010). The startup delay where the config is loaded from the keyboard should also be shorter now.

In addition, I've provided pre-built ATMega images. Those are identical in functionality. The only difference is the reported type of Keyboard (A500, A500Mini or A3000) as reflected by the Amiga configuration program.

An example flashing procedure is outlined in the updated Readme in the "src/" subdirectory. As I am avoiding Windows as far as possible (Amiga aficinado, after all), I do perform ATMega flashing using AVRDude.

HenrykRichter, 2023-08-19:
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

> I can see the CLK/KDATA on the PCB near RST and 5V+ so I'm guessing these are KBCLOCK/KBDATA that you're referring to. What I'm not sure about is "use IN3/IN4 for Amiga communication", what do you mean by that?

Sorry about the confusion. What you've stumbled over were essentially my notes for the case that I should need ATMega-side serial debugging output in the future.

The regular builds of the ATMega software will result in an intuitive pinout provided by the firmware, where you need 4 wires left, 3 wires right on the main set of holes, exactly matching what the A500 keyboard connector has. The two additional pins (IN3,IN4) can take low-active sources (HDDs,Network etc.) that can be reflected on any of the LED's.

gotnull, 2023-08-22:
So I'm having issues trying to find the correct parts for: D53, D52, D51, D7, D1, D6, D5

I thought the correct parts were: CLV1A-FKB-CK1VW1DE1BB7C3C3 although they don't seem to fit according to this:

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

The yellow is the pins of the part and the green is the pad on the PCB.

Any idea what the correct part numbers are. I'm using JLCPCB who've come back with this issue.

HenrykRichter, 2023-08-24:
> I thought the correct parts were: CLV1A-FKB-CK1VW1DE1BB7C3C3 although they don't seem to fit according to this:
Those LEDs are indeed "Common Anode" but have a different pin assignment than those I've fitted. Please note that those Cree LEDs would have to be mounted 180 degrees rotated to have the Anode at the +5V pad. Also (as noted before), the R,G,B assignments are different.

An example for LEDs with the correct R,G,B assignment would be from Würth, order no 150141M173100. This type of LED would also needed to be mounted with 180° rotation, though.

I am aware that the pads are not long enough for automated PCB population with solder paste under the LEDs as the PCB was designed with hand soldering in mind. What I could offer is to re-design the LED part for those Würth LEDs, so that both pads and orientation are usable with automated part population processes.

I'll post here once I find some time re-doing the PCBs.

gotnull, 2023-08-24:
That would be terrific, thank you!

gotnull, 2023-08-24:
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

That would be terrific, thank you!

kavanoz64, 2023-08-28:
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

There is no fully Amiga compatible Cherry MX keycaps. Henryk had recommended to use Mitsumi mechanical switches used on A1000 keyboards. These fell like Cherry MX Brown (silent) and are compatible with a1200.net keycap sets.
https://www.ebay.com/itm/325236069397
https://www.aliexpress.us/item/2251832448720693.html

gotnull, 2023-08-29:
> An example flashing procedure is outlined in the updated Readme in the "src/" subdirectory. As I am avoiding Windows as far as possible (Amiga aficinado, after all), I do perform ATMega flashing using AVRDude.

Thanks for the information. I see the updated Readme, however it doesn't explain which of the 6 pins to use for flashing.

gotnull, 2023-08-29:
> An example flashing procedure is outlined in the updated Readme in the "src/" subdirectory. As I am avoiding Windows as far as possible (Amiga aficinado, after all), I do perform ATMega flashing using AVRDude.

I have a couple of ST-LINK V2 (STM8 & STM32) compatible USBasp programmers, it would be good to know which of the 6 pins connect to the PCB.

I no longer have the 10->6 pin cable that came with mine so without knowing which pins go where it's becoming confusing.

gotnull, 2023-08-30:
@HenrykRichter are you able to confirm the current wiring is correct?

I’ve flashed the A500.hex via avrdude and it’s flashed successfully.

I’ve also opened the A500KBConfig but the popup dialog, which says:

Loading current configuration from A500 keyboard…
ATT : DON’T TOUCH ANY KEY UNTIL THE REQUESTER DISAPPEARS!

This process might take some seconds

It never actually disappears for me on my A500. I am noticing that the CAPS LED flashes every few seconds though.

If I click cancel it takes me it does take me to the Config. If I click Save EEPROM that also seems to save, however I don’t have any LED’s soldered yet.

Now if I access CLI it seems as if the SPACEBAR is constantly pressed down.

Any ideas what might be wrong?

gotnull, 2023-08-31:
@kavanoz64 any ideas?

kavanoz64, 2023-08-31:
I installed all 7 RBG LEDs and was able to configure them using the app running under OS 3.2.1. I suggest you check all the connections and maybe install the LEDs if you have them. My CTRL key was initially not working (except it was resetting using CTRL+A+A). After using the app CTRL key is also working.
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
kavanoz64, 2023-09-02:
I tested another PCB with ICs soldered without LEDs and switches. Programming worked fine and the keyboard also worked. I was able to use the utility in Amiga OS and keys were working when I shorted the pins. So if you are getting the same result on 2 PCBs, either there is a problem with the production or some incompatibility with your machine. Do you have another Amiga to test it?

gotnull, 2023-09-02:
> I tested another PCB with ICs soldered without LEDs and switches. Programming worked fine and the keyboard also worked. I was able to use the utility in Amiga OS and keys were working when I shorted the pins. So if you are getting the same result on 2 PCBs, either there is a problem with the production or some incompatibility with your machine. Do you have another Amiga to test it?

Thanks for doing this, I wonder if it’s the rotation of some of the SMD’s and diodes that’s the problem? If you have time can you send me close up screenshots of all your components and some diodes?

Any idea how much shipping would cost from US to Australia? :/

kavanoz64, 2023-09-02:
Shipping will cost about $20 using PirateShip Simple Export service. This is what I usually use when shipping stuff to AU.
Keys were working before running the config utility.
Here is some close up photos.
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

gotnull, 2023-09-02:
> Shipping will cost about $20 using PirateShip Simple Export service. This is what I usually use when shipping stuff to AU.

I would be absolutely fine with paying $20 for the shipping to AU if you’re happy posting it.

Thanks for the closeup photos. All the diodes seem to be the correct orientation and everything else like you said seems to be correct.

kavanoz64, 2023-09-03:
Send me an email. I am using the most well known email service with the same username here.

gotnull, 2023-09-03:
> Send me an email. I am using the most well known email service with the same username here.

Thanks, email sent!

HenrykRichter, 2023-09-05:
> Perhaps you could attach your A500KBConfig file and I could test that? I tried using the one straight from this repository but it doesn't execute on my A500.
Probably the executable flag got missing when transferring that file, perhaps
`Protect A500KBConfig +e `
will be sufficient (from CLI). Otherwise, those warnings by the compiler are harmless. Different versions of the AmigaOS SDK have different data types for the same outcome.

HenrykRichter, 2023-09-05:
> `avrdude error: cannot set sck period; please check for usbasp firmware update`

This warning typically shows with the reduced USBasp clones from China that don't have the SCK speed jumper. Those Clones tend to work just fine (I have one, too) but won't support fast flashing.

HenrykRichter, 2023-09-05:
> @HenrykRichter are you able to confirm the current wiring is correct?

The wiring will work, although one of the cables is superflous. The A500 keyboard connector has a key pin, which is pin5. So wiring needs to address pins 1-4 and pins 6-8. In your case of the picture, the black wire is not needed (but doesn't hurt, either).

gjorans, 2023-09-15:
Sorry to ask this but I am very newbie on this. Is there a Zero to hero guide for making this? what to upload at pcbway etc? I am totally lost (but know how to solder).

HenrykRichter, 2023-09-25:
> Sorry to ask this but I am very newbie on this. Is there a Zero to hero guide for making this? what to upload at pcbway etc? I am totally lost (but know how to solder).
This project is relatively complex, due to a combination of PCBs (which need a mix of SMD and THT soldering), a uC that needs programming and 3D printed parts.

The biggest obstacle to overcome in the planning phase is the combination of keyswitches and matching keycaps. There is one option of procuring Mitsumi switches, for which new keycaps are available. Otherwise, Cherry (or compatible) switches may be mounted, too. The downside for Cherry MX, however is that I know of just one person (kipper2k) who has been able to obtain a full Amiga compatible set of keycaps (from an undisclosed source).

I don't know if PCBWay accepts the Gerber files I've prepared. So far, I only ordered with JLCPCB. To order a PCB, you basically just need to zip the contents of the "A500KB_Gerber" folder, upload that to the site and enter some basic information (HASL is OK for this type of PCB, 2mm thickness to make it somewhat sturdy). The second PCB production files are "A500KBPlate_Gerber". The plate should be 1mm. It can be made out of FR4 (like most other PCBs) or (in case of JLCPCB) also Aluminum.

Closed 2023-12-18.

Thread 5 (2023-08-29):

CTRL key implementation

kavanoz64, 2023-08-29:
Hi Henryk,

Thank you for this great project and the support you have been providing. I finally built the keyboard and got it working. So far my testing shows all the keys as working except the CTRL key. CTRL+AMIGA+AMIGA is working to reset the computer so physical connection with the switch should not be an issue.

AmigaOS Documentation Wiki (https://wiki.amigaos.net/wiki/Keymap_Library) says: "When pressed with CTRL alone, alphabetic keys should generally transmit their unshifted value but with bits 5 and 6 cleared. This allows keyboard typing of "control characters." For example, the C key (normally value $63) should transmit value $03 (Ctrl-C) when Ctrl and C are pressed together."

I looked at the source code for the ATMega32 and couldn't see the code to accomplish this (though I am not an expert on this and may have missed it). Can you please confirm if this is the case and whether you are planning to add the functionality?

gotnull, 2023-08-29:
Can you please go through the firmware flashing process? I've built my own keyboards but wasn't sure what software to use to flash and what pins to use.

kavanoz64, 2023-08-31:
Today, I installed TF536 and booted to Amiga OS using CF-IDE. I ran the config app, adjusted my led colors and saved to EEPROM. Later when trying a few other things, I noticed in ATK that CTRL key was working. Then I tried CTRL+C and it successfully executed break operation on a running app in the CLI. So the key is working after all.

kavanoz64, 2023-08-31:
Closing this issue as it wasn't an issue after all.

HenrykRichter, 2023-08-31:
:-)
The keyboard does not contain modifier logic. It just transmits scancodes that are interpreted by the system (keymap.library) wrt. qualifiers. The only exception is the 3 finger salute.

kavanoz64, 2023-09-01:
Tonight, I tried again with the 68000 CPU and CTRL didn't work again. Then I tried with Matze's 68030-TK2 and it worked. So on my A500 (rev 6 with 1 MB RAM), it only works with accelerators so far. I have another A500 and a 500+. I'll try with them as well.

HenrykRichter, 2023-09-03:
I don't think that this CTRL issue is related to the Amiga connection or the firmware since all keycodes are transmitted in exactly the same way. Are you on the latest firmware (from 2-Aug)? I've changed the timing for subsequent (or simultaneuos) keycode transmission to wait a little longer between transmitted keystrokes in that version. I just checked CTRL-C with a slow (68010) A500 and it worked just fine for me.

What I suspect is an electrical issue, where there is either a soldering problem (pls check pin 13 of the ATMega) or the particular switch has a connectivity problem (internal or external). I found that I had to clean the pins of my Mitsumi switches before soldering when I've built my Keyboards.

Closed 2023-08-31.

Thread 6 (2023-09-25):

Sorry to ask this but I am very newbie on this. Is there a Zero to hero guide for making this? what to upload at pcbway etc? I am totally lost (but know how to solder).

gotnull, 2023-09-25:
Sorry to ask this but I am very newbie on this. Is there a Zero to hero guide for making this? what to upload at pcbway etc? I am totally lost (but know how to solder).

_Originally posted by @gjorans in https://github.com/HenrykRichter/A500KB/issues/4#issuecomment-1721801390_

Closed 2023-12-18.

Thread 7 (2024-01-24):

A1200 compatibility

jcagigal, 2024-01-24:
Hi! As a feature request for the next revisions perhaps you could make It also A1200 compatible performing some small changes to make the small controller board dettachable so the main keyboard part fits in an A1200 case. Or maybe just splitting the big leds using a few pins/connector allowing the user to "dettach" the leds part if he's going to use an A1200.

Perhaps allowing to solder a connector like 32way Molex 52044-3245 underside so a long flat cable like Molex 15168-0400 can be connected to A1200 connector. One of the extra connections could be cut down from the flat cable so It fits into the A1200 keyboard connector.

Anyway great job. It would be cool if you could post pictures using standard cherry keycaps too. What do you think about using a 3d printed mitsumi-low profile cherry adapter to use original keys?

HenrykRichter, 2024-01-25:
From my perspective, the A1200 is out of scope. It's certainly possible to modify the existing PCB layout by removing the controller section. Then again, my main motivation (besides the use of mechanical keys) was to get something simlar to BiFrost on A500s. If you are looking for an A1200 Keyboard, there already is the approach by Aeberbach (https://github.com/aeberbach/A1200KB).

Concerning adapters: Some years back I built a custom Amiga keyboard using 3D printed adapters to fit Mitsumi A500 keycaps to Alps keys. While (surprisingly) the adapters work fine and the keys still feel natural and klick happily, the added height made it unsuitable for classic enclosures. My conclusion was that probably the better option would be to replicate the Cherry stem with a Mitsumi compatible opening and modify Cherry keys with those. I'm unsure if resin printed parts would be strong enough. As far as I've read, at least two people have looked at this route (Phil from A1200.net, Kipper on EAB). That being said: The low profile switches may still fit with an adapter but I didn't try.

Closed 2024-02-05.

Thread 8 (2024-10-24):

J1/Molex 39-53-2314 is Unavailable

ajacocks, 2024-10-24:
Is there a replacement for the unavailable Molex 39-53-2314? None of the big parts houses seems to have it in stock, or on order. I searched for alternate 31 pin FFCs, but couldn't find any.

HenrykRichter, 2024-10-25:
Connectors with 1.25mm pitch are not easy to get these days. One alternative to the Molex part would be TE/AMP 3-84533-1 (which is also out of stock at the places I frequent).

A UK retro shop is selling re-designed A500 keyboard controllers lately which have a non-ZIF connector. Maybe those people behind it could offer some insight on parts availability.

ajacocks, 2024-10-25:
Well, one option might be a sub board to mount the vertical version at 90 degrees:
https://www.molex.com/en-us/products/part-detail/39532315

Think that would fit? That part seems to be available.

HenrykRichter, 2024-12-02:
Sorry for the late answer. I'm not sure that the connector could be positioned reliably when building a VERT-ANGLED adapter (manually or by PCB).

One workaround that might be worth a shot would be a 32 pin angled connector where Pin32 is just clipped off.

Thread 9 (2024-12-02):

USB Testing Failure

ajacocks, 2024-12-02:
I have completed the basic build of the keyboard PCB, and gotten it programmed:

```
$ avrdude -c stk500v2 -P "$PORT" -p $MCU -U flash:w:A500.hex:i
Reading 9162 bytes for flash from input file A500.hex
Writing 9162 bytes to flash
Writing | ################################################## | 100% 0.51 s
Reading | ################################################## | 100% 0.33 s
9162 bytes of flash verified

Avrdude done.  Thank you.
$ avrdude -c stk500v2 -P "$PORT" -p $MCU -U hfuse:w:0x91:m -U lfuse:w:0xdf:m

Processing -U hfuse:w:0x91:m
Reading 1 byte for hfuse from input file 0x91
Writing 1 byte (0x91) to hfuse, 1 byte written, 1 verified

Processing -U lfuse:w:0xdf:m
Reading 1 byte for lfuse from input file 0xdf
Writing 1 byte (0xDF) to lfuse, 1 byte written, 1 verified

Avrdude done.  Thank you.
```

When I attempt to connect the keyboard to a Linux x64 host to verify that key signals are being sent, I get errors when attaching the keyboard via microUSB:

```
[  600.504522] usb 3-3: new full-speed USB device number 11 using xhci_hcd
[  600.684449] usb 3-3: device descriptor read/64, error -71
[  600.967895] usb 3-3: device descriptor read/64, error -71
[  601.254454] usb 3-3: new full-speed USB device number 12 using xhci_hcd
[  601.434564] usb 3-3: device descriptor read/64, error -71
[  601.717874] usb 3-3: device descriptor read/64, error -71
[  601.821341] usb usb3-port3: attempt power cycle
[  602.274395] usb 3-3: new full-speed USB device number 13 using xhci_hcd
[  602.274612] usb 3-3: Device not responding to setup address.
[  602.478013] usb 3-3: Device not responding to setup address.
[  602.681161] usb 3-3: device not accepting address 13, error -71
[  602.681411] usb 3-3: WARN: invalid context state for evaluate context command.
```

...and the keyboard is not seen in `lsusb`:
```
$ lsusb
Bus 001 Device 001: ID 1d6b:0002 Linux Foundation 2.0 root hub
Bus 002 Device 001: ID 1d6b:0003 Linux Foundation 3.0 root hub
Bus 003 Device 001: ID 1d6b:0002 Linux Foundation 2.0 root hub
Bus 003 Device 002: ID 0bda:5634 Realtek Semiconductor Corp. Laptop Camera
Bus 003 Device 003: ID 27c6:609c Shenzhen Goodix Technology Co.,Ltd. Goodix Fingerprint USB Device
Bus 003 Device 005: ID 8087:0036 Intel Corp.
Bus 004 Device 001: ID 1d6b:0003 Linux Foundation 3.0 root hub
```

Here are the relevant parts of the PCB:
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

ajacocks, 2024-12-02:
And here is the status of the LEDs when connected to a computer via USB:
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

HenrykRichter, 2024-12-02:
The static LED scheme (R,G,B) is the indicator that the Keyboard went into USB mode. That part is expected.

Right off the bat, I can't say yet with confidence why the initial communication with the host failed. This is something I didn't run into when testing the USB mode with my own builds (Mac Pro, Linux Laptop, Amiga+Freeway+Poseidon).  One possibility is a clock issue where the ATMega doesn't run at the intended speed. Another possibility is a broken AT90USB1287.

What I didn't test as of yet on the software side is to connect the Keyboard to a USB-3 host. Maybe USB-3 hosts initialize devices differently from USB-1/-2.

ajacocks, 2024-12-03:
Ah, interesting. The port is on a Framework 13, and is USB 3.2 gen 2. I’ll try to attach it to a USB 2.0 port and see what happens.

ajacocks, 2024-12-03:
After testing on an older ThinkPad X61, running Linux, I can confirm that all the keys seem to work as expected, except for some keymapping oddities that I had expected.

So, yes, it appears that USB3 initialization is the issue on the Framework. Is there any data that you would like me to capture?

HenrykRichter, 2024-12-03:
While I'm going to check this issue out myself, some traces and logs are certainly of help (i.e. Wireshark captures or screenshots of failed commands).

ajacocks, 2024-12-03:
As a side note, you might want to mention that the standard [Atmel AVR ISP Mk2](https://ww1.microchip.com/downloads/en/DeviceDoc/Atmel-42093-AVR-ISP-mkII_UserGuide.pdf) does not provide 5Vdc. I had forgotten that, and thought that my board was completely dead, until I checked the voltages.

Closed 2025-04-14.

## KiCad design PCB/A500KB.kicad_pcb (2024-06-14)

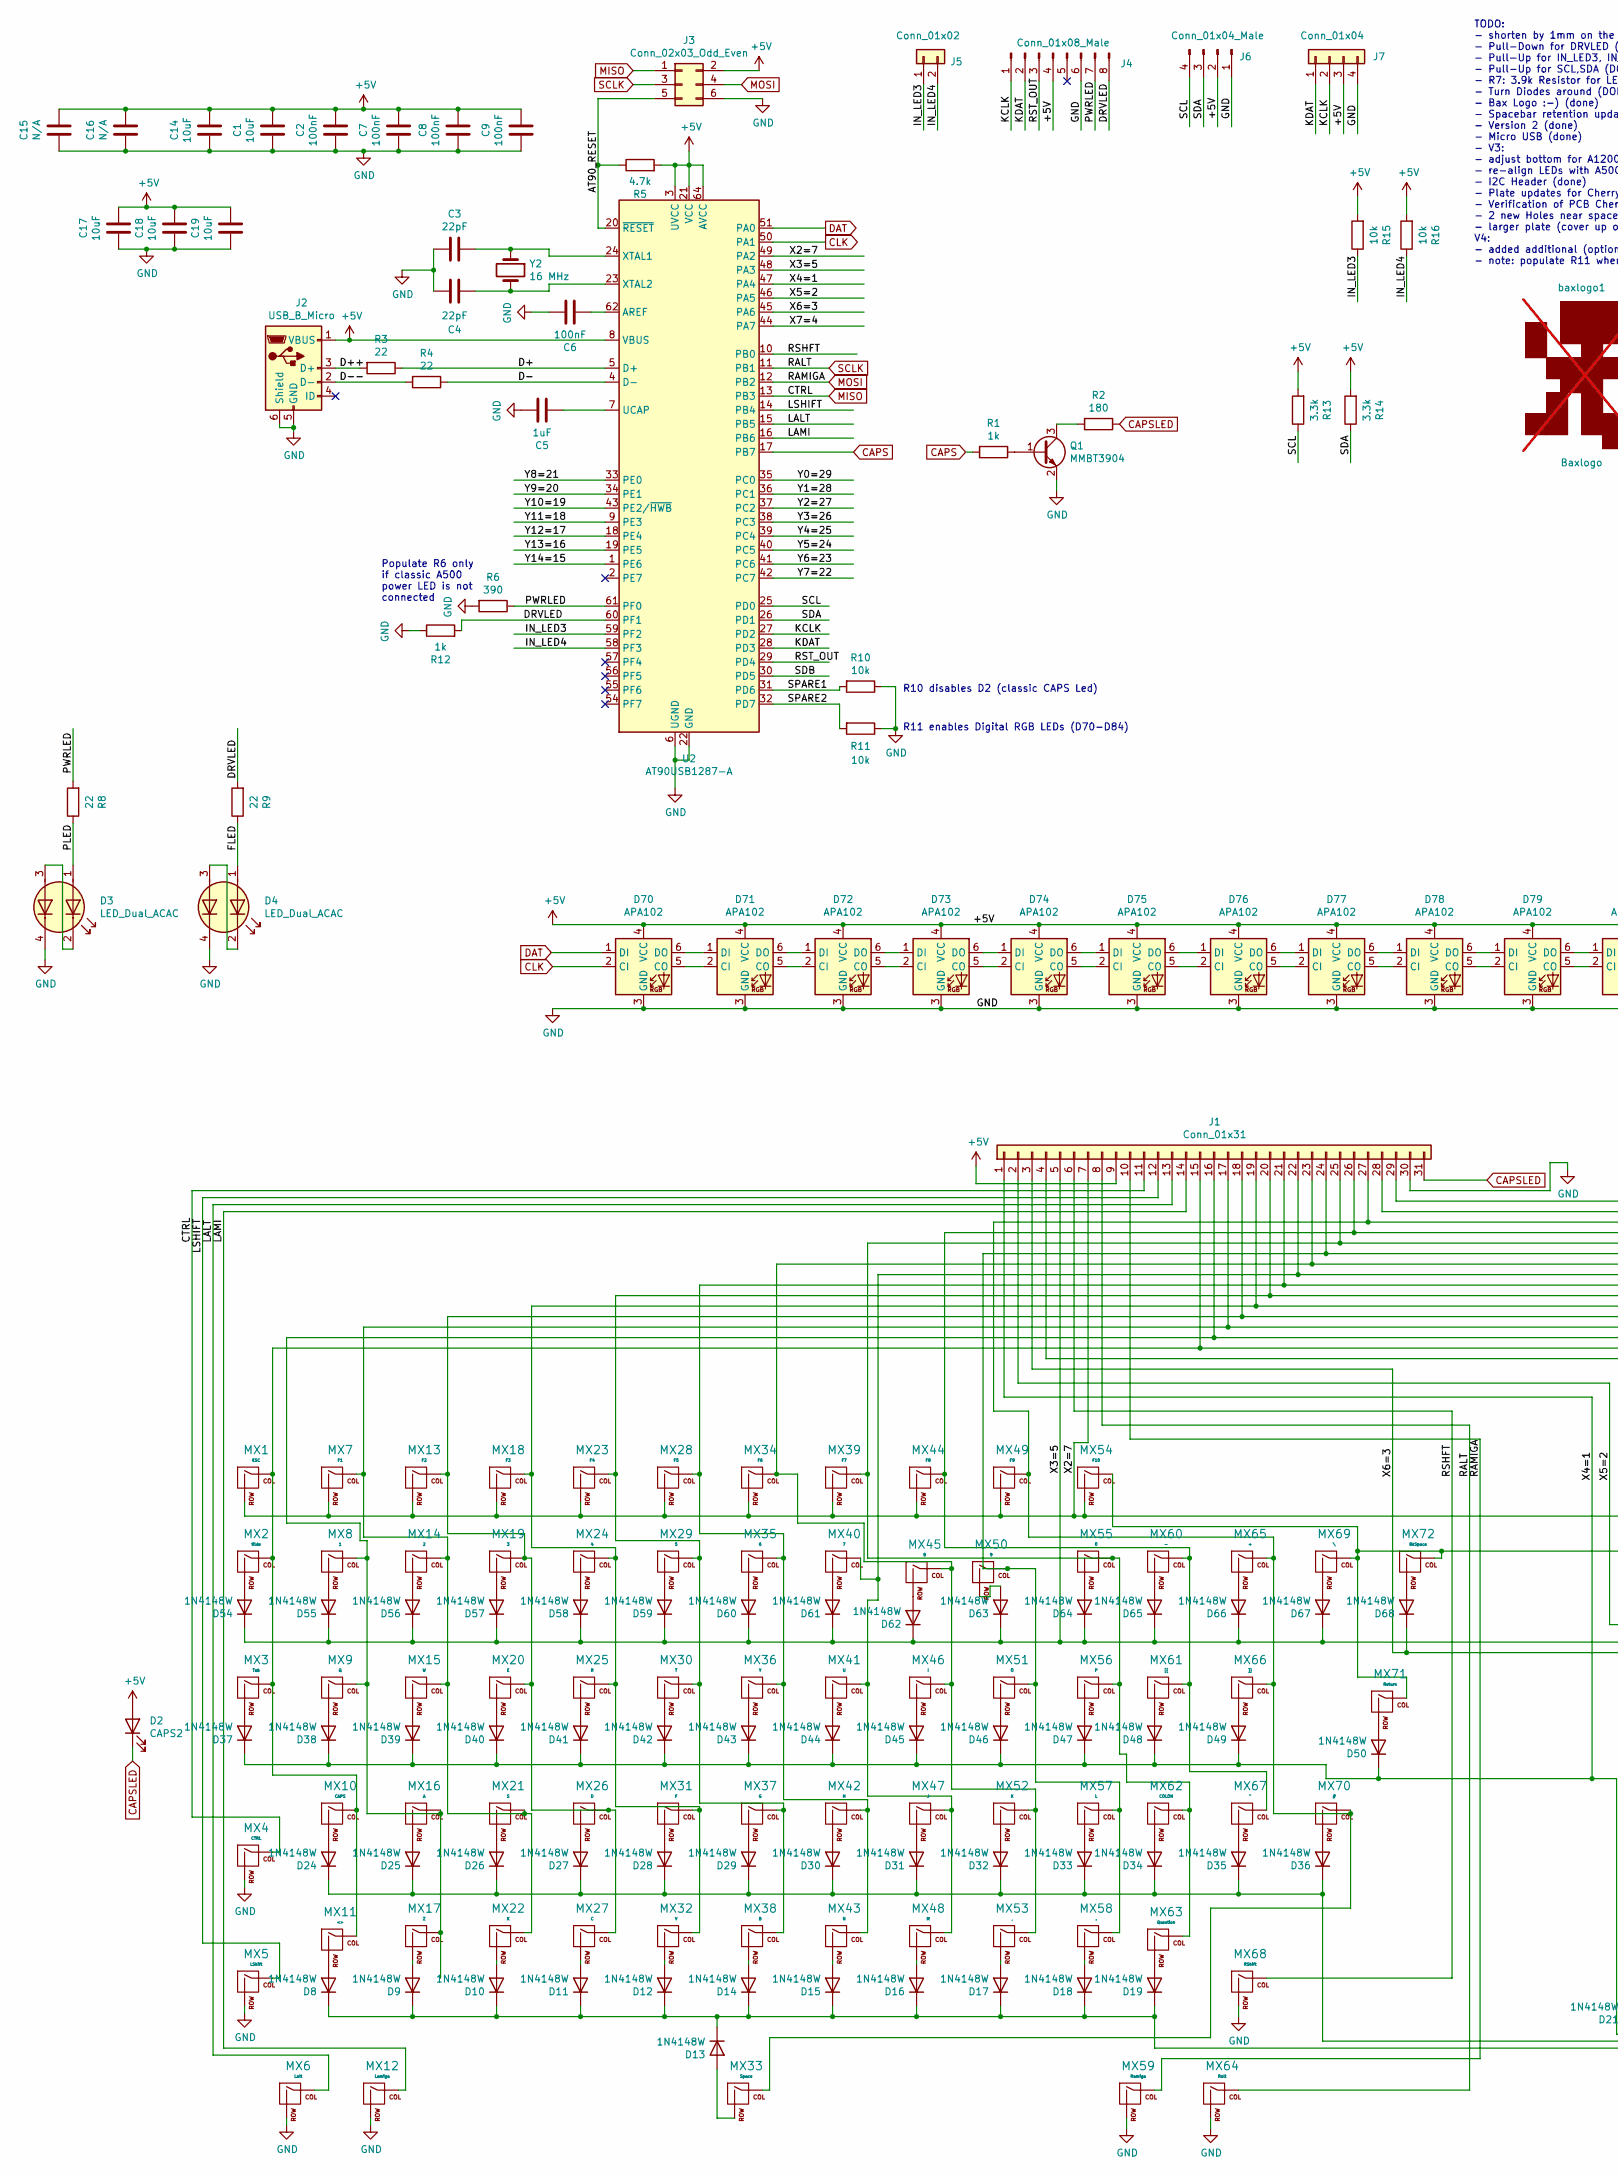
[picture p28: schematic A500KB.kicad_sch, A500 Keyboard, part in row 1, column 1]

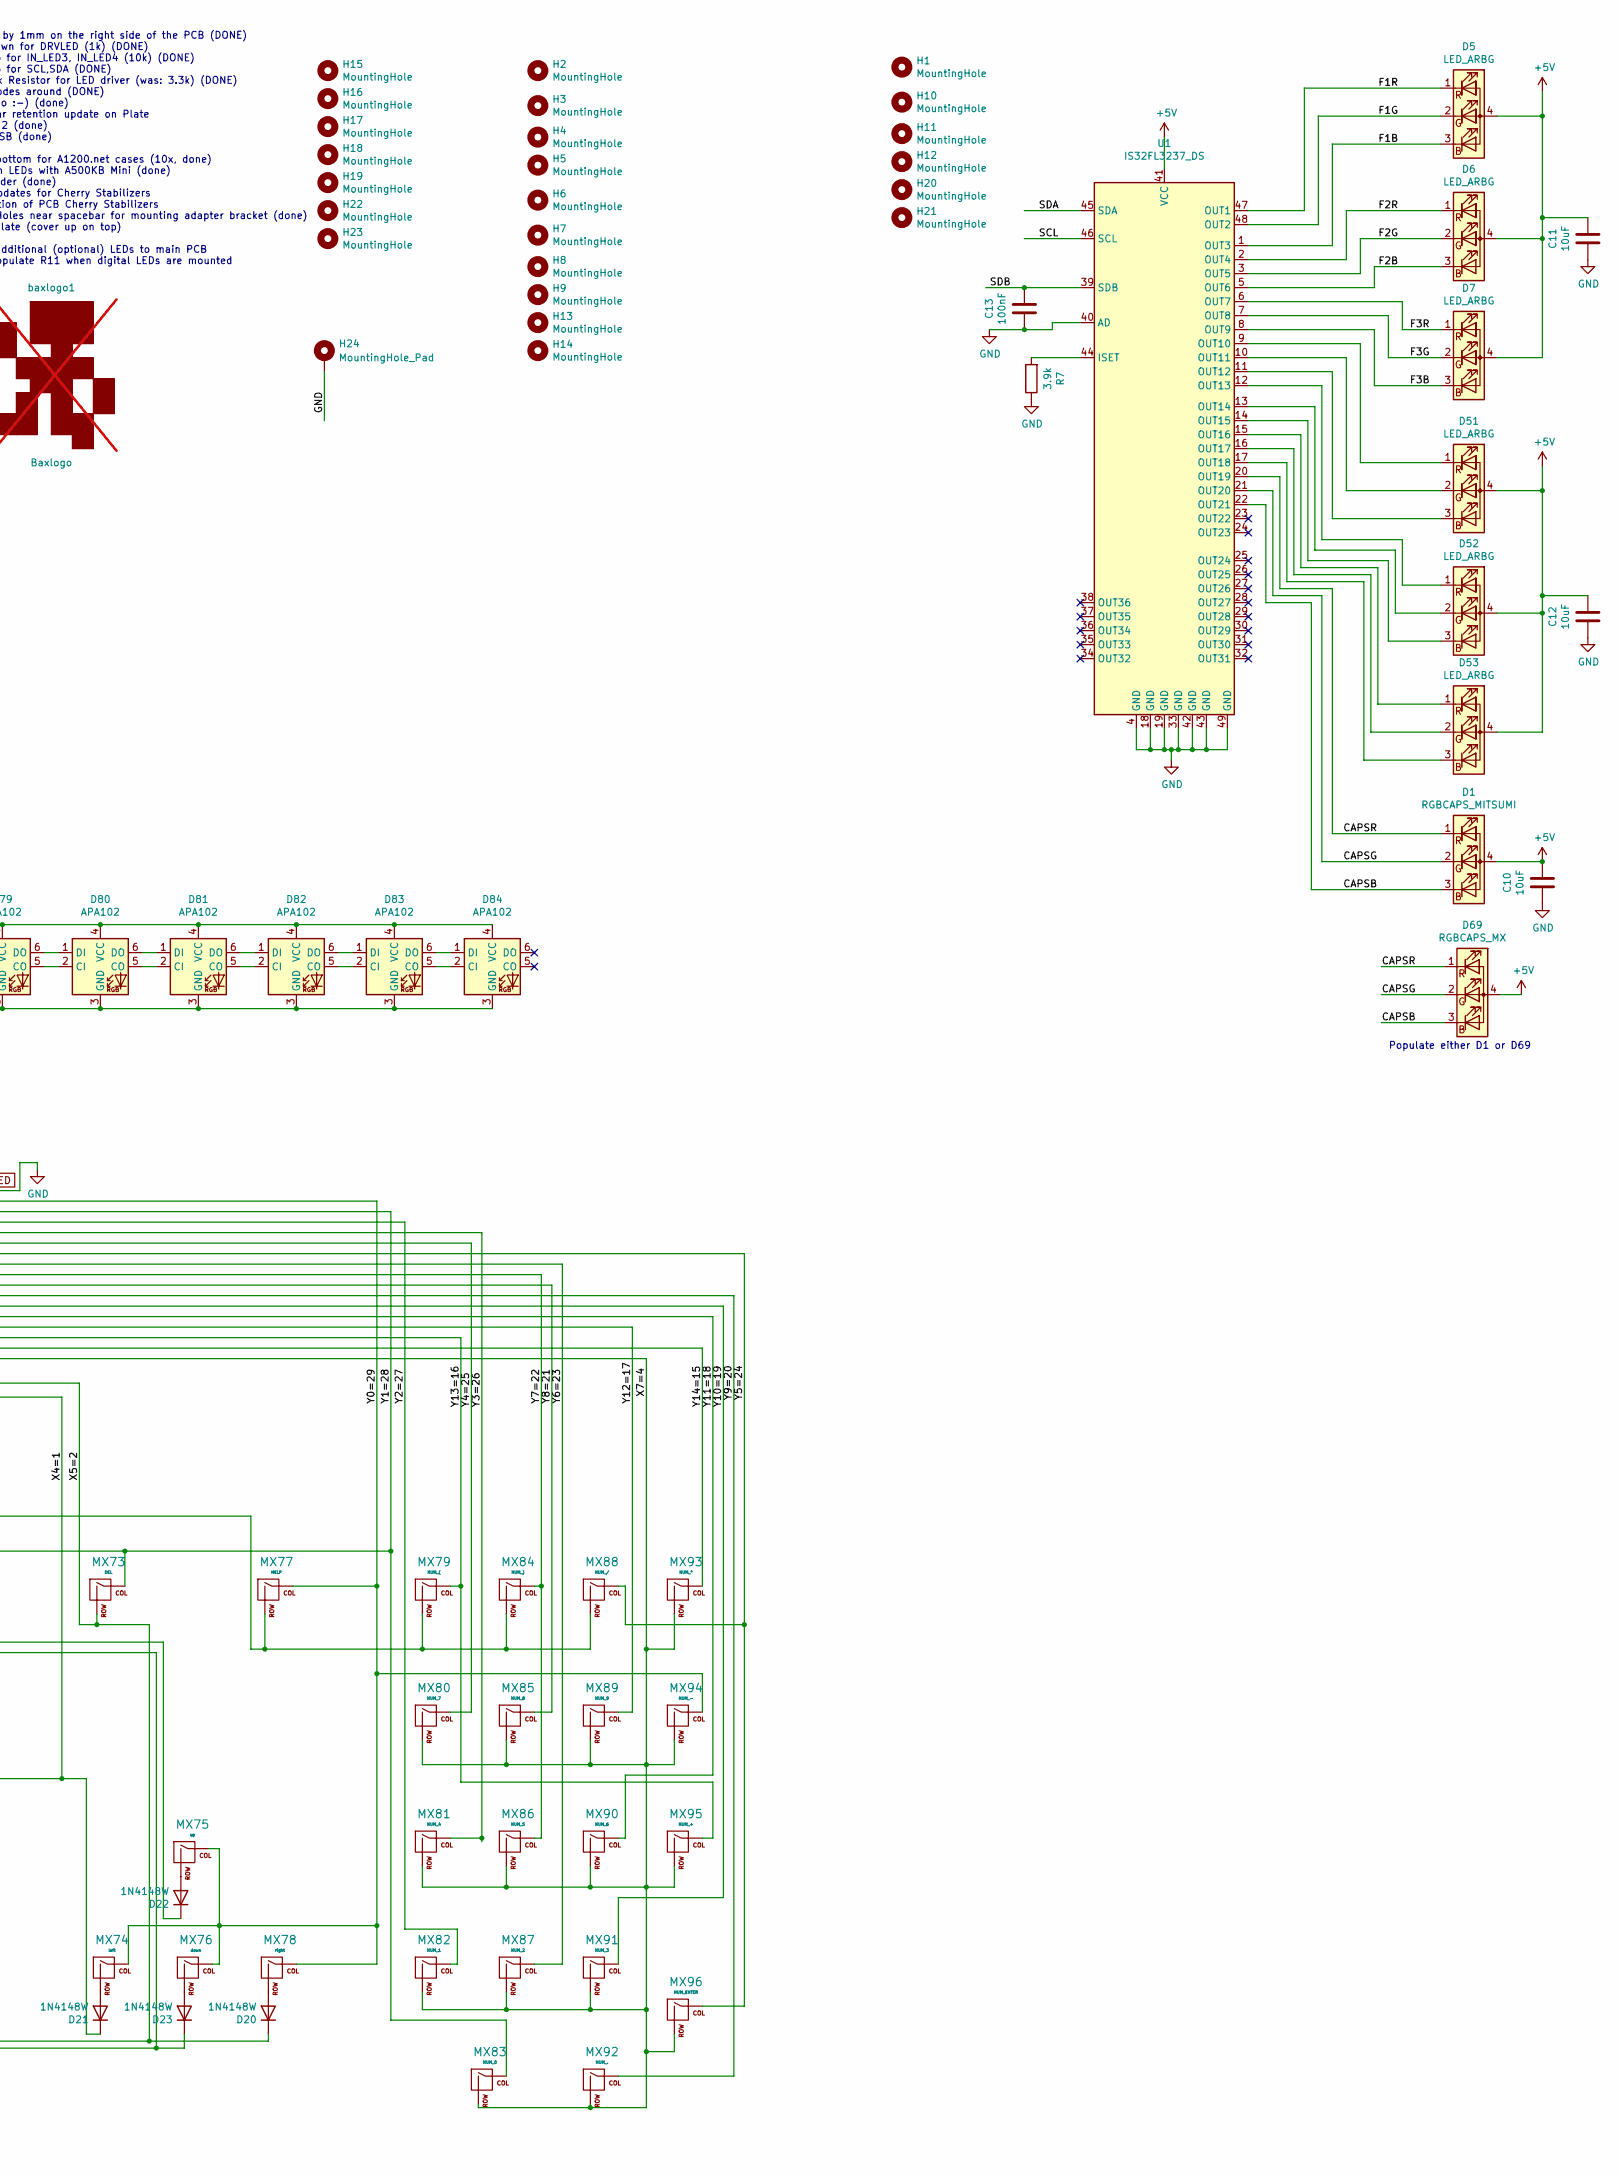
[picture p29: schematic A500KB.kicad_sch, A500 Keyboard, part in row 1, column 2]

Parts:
C1, C10, C11, C12, C14, C17, C18, C19: 10uF; C_0805_2012Metric_Pad1.18x1.45mm_HandSolder; LCSC C15850
C2, C6, C7, C8, C9, C13: 100nF; C_0805_2012Metric_Pad1.18x1.45mm_HandSolder; LCSC C49678
C3, C4: 22pF; C_0805_2012Metric_Pad1.18x1.45mm_HandSolder; LCSC C1804
C5: 1uF; C_0805_2012Metric_Pad1.18x1.45mm_HandSolder; LCSC C28323
C15, C16: N/A; C_Elec_6.3x5.8
D1: RGBCAPS_MITSUMI; LED_Cree-PLCC4_3.2x2.8mm_CCW; digikey 732-4998-1-ND
D2: CAPS2; D_0805_2012Metric_Pad1.15x1.40mm_HandSolder; LCSC C688883
D3, D4: LED_Dual_ACAC; LED_DUAL_A500
D5: LED_ARBG; LED_Cree-PLCC4_3.2x2.8mm_CCW; digikey 1516-1195-1-ND
D6, D7, D51, D52, D53: LED_ARBG; LED_Cree-PLCC4_3.2x2.8mm_CCW; LCSC C5342281
D8, D9, D10, D11, D12, D13, D14, D15, D16, D17, D18, D19, D20, D21, D22, D23, D24, D25, D26, D27, D28, D29, D30, D31, D32, D33, D34, D35, D36, D37, D38, D39, D40, D41, D42, D43, D44, D45, D46, D47, D48, D49, D50, D54, D55, D56, D57, D58, D59, D60, D61, D62, D63, D64, D65, D66, D67, D68: 1N4148W; D_SOD-123; LCSC C444720
D69: RGBCAPS_MX; LED_Cree-PLCC4_3.2x2.8mm_CCW; digikey 732-4998-1-ND
D70, D71, D72, D73, D74, D75, D76, D77, D78, D79, D80, D81, D82, D83, D84: APA102; LED_RGB_5050-6; LCSC C5378730
H1, H2, H3, H4, H5, H6, H7, H8, H9, H10, H11, H12, H13, H14, H20, H21: MountingHole; MountingHole_3.2mm_M3_Small_Bax
H15, H16, H17, H18, H22, H23: MountingHole; MountingHole_2.5mm
H19: MountingHole; MountingHole_4.3mm_M4
H24: MountingHole_Pad; MountingHole_2.5mm_Pad_TopBottom
J1: Conn_01x31; FFC-1.25mm-Molex-39-53-2314
J2: USB_B_Micro; USB_Micro-B_Molex-105017-0001; Mouser 538-105017-0001
J3: Conn_02x03_Odd_Even; PinHeader_2x03_P2.54mm_Vertical; LCSC C32713276
J4: Conn_01x08_Male; PinHeader_1x08_P2.54mm_Vertical; LCSC C2935933
J5: Conn_01x02; PinHeader_1x02_P2.54mm_Vertical
J6: Conn_01x04_Male; PinHeader_1x04_P2.54mm_Vertical
J7: Conn_01x04; JST_EH_S4B-EH_1x04_P2.50mm_Horizontal; LCSC C265068
MX1: ESC; MXMitsumi-1U-NoLED
MX2: tilde; MXMitsumi-1.5U-NoLED
MX3: Tab; MXMitsumi-2U-NoLED
MX4: CTRL; MXMitsumi-1.25U-NoLED
MX5: LShift; MXMitsumi-1.75U-NoLED
MX6: Lalt; MXMitsumi-1.25U-NoLED
MX7: F1; MXMitsumi-1.25U-NoLED
MX8: 1; MXMitsumi-1U-NoLED
MX9: Q; MXMitsumi-1U-NoLED
MX10: CAPS; MXMitsumi-1U-NoLED
MX11: <>; MXMitsumi-1U-NoLED
MX12: Lamiga; MXMitsumi-1.25U-NoLED
MX13: F2; MXMitsumi-1.25U-NoLED
MX14: 2; MXMitsumi-1U-NoLED
MX15: W; MXMitsumi-1U-NoLED
MX16: A; MXMitsumi-1U-NoLED
MX17: Z; MXMitsumi-1U-NoLED
MX18: F3; MXMitsumi-1.25U-NoLED
MX19: 3; MXMitsumi-1U-NoLED
MX20: E; MXMitsumi-1U-NoLED
MX21: S; MXMitsumi-1U-NoLED
MX22: X; MXMitsumi-1U-NoLED
MX23: F4; MXMitsumi-1.25U-NoLED
MX24: 4; MXMitsumi-1U-NoLED
MX25: R; MXMitsumi-1U-NoLED
MX26: D; MXMitsumi-1U-NoLED
MX27: C; MXMitsumi-1U-NoLED
MX28: F5; MXMitsumi-1.25U-NoLED
MX29: 5; MXMitsumi-1U-NoLED
MX30: T; MXMitsumi-1U-NoLED
MX31: F; MXMitsumi-1U-NoLED
MX32: V; MXMitsumi-1U-NoLED
MX33: Space; MXMitsumi-9U-NoLED
MX34: F6; MXMitsumi-1.25U-NoLED
MX35: 6; MXMitsumi-1U-NoLED
MX36: Y; MXMitsumi-1U-NoLED
MX37: G; MXMitsumi-1U-NoLED
MX38: B; MXMitsumi-1U-NoLED
MX39: F7; MXMitsumi-1.25U-NoLED
MX40: 7; MXMitsumi-1U-NoLED
MX41: U; MXMitsumi-1U-NoLED
MX42: H; MXMitsumi-1U-NoLED
MX43: N; MXMitsumi-1U-NoLED
MX44: F8; MXMitsumi-1.25U-NoLED
MX45: 8; MXMitsumi-1U-NoLED
MX46: I; MXMitsumi-1U-NoLED
MX47: J; MXMitsumi-1U-NoLED
MX48: M; MXMitsumi-1U-NoLED
MX49: F9; MXMitsumi-1.25U-NoLED
MX50: 9; MXMitsumi-1U-NoLED
MX51: O; MXMitsumi-1U-NoLED
MX52: K; MXMitsumi-1U-NoLED
MX53: ,; MXMitsumi-1U-NoLED
MX54: F10; MXMitsumi-1.25U-NoLED
MX55: 0; MXMitsumi-1U-NoLED
MX56: P; MXMitsumi-1U-NoLED
MX57: L; MXMitsumi-1U-NoLED
MX58: .; MXMitsumi-1U-NoLED
MX59: Ramiga; MXMitsumi-1.25U-NoLED
MX60: -; MXMitsumi-1U-NoLED
MX61: [{; MXMitsumi-1U-NoLED
MX62: COLON; MXMitsumi-1U-NoLED
MX63: Question; MXMitsumi-1U-NoLED
MX64: Ralt; MXMitsumi-1.25U-NoLED
MX65: +; MXMitsumi-1U-NoLED
MX66: ]}; MXMitsumi-1U-NoLED
MX67: "; MXMitsumi-1U-NoLED
MX68: RShift; MXMitsumi-2.75U-NoLED
MX69: \; MXMitsumi-1U-NoLED
MX70: #; MXMitsumi-1U-NoLED
MX71: Return; MXMitsumi-ISO-NoLED
MX72: BkSpace; MXMitsumi-1U-NoLED
MX73: DEL; MXMitsumi-1.5U-NoLED
MX74: left; MXMitsumi-1U-NoLED
MX75: up; MXMitsumi-1U-NoLED
MX76: down; MXMitsumi-1U-NoLED
MX77: HELP; MXMitsumi-1.5U-NoLED
MX78: right; MXMitsumi-1U-NoLED
MX79: NUM_(; MXMitsumi-1U-NoLED
MX80: NUM_7; MXMitsumi-1U-NoLED
MX81: NUM_4; MXMitsumi-1U-NoLED
MX82: NUM_1; MXMitsumi-1U-NoLED
MX83: NUM_0; MXMitsumi-2U-NoLED
MX84: NUM_); MXMitsumi-1U-NoLED
MX85: NUM_8; MXMitsumi-1U-NoLED
MX86: NUM_5; MXMitsumi-1U-NoLED
MX87: NUM_2; MXMitsumi-1U-NoLED
MX88: NUM_/; MXMitsumi-1U-NoLED
MX89: NUM_9; MXMitsumi-1U-NoLED
MX90: NUM_6; MXMitsumi-1U-NoLED
MX91: NUM_3; MXMitsumi-1U-NoLED
MX92: NUM_.; MXMitsumi-1U-NoLED
MX93: NUM_*; MXMitsumi-1U-NoLED
MX94: NUM_-; MXMitsumi-1U-NoLED
MX95: NUM_+; MXMitsumi-1U-NoLED
MX96: NUM_ENTER; MXMitsumi-2U-VerticalStabilizers-NoLED
Q1: MMBT3904; SOT-23; LCSC C20526
R1, R12: 1k; R_0805_2012Metric_Pad1.20x1.40mm_HandSolder; LCSC C17513
R2: 180; R_0805_2012Metric_Pad1.20x1.40mm_HandSolder; LCSC C25270
R3, R4, R8, R9: 22; R_0805_2012Metric_Pad1.20x1.40mm_HandSolder; LCSC C17561
R5: 4.7k; R_0805_2012Metric_Pad1.20x1.40mm_HandSolder; LCSC C17673
R6: 390; R_0805_2012Metric_Pad1.20x1.40mm_HandSolder; LCSC C17655
R7: 3.9k; R_0805_2012Metric_Pad1.20x1.40mm_HandSolder; LCSC C17614
R10, R11, R15, R16: 10k; R_0805_2012Metric_Pad1.20x1.40mm_HandSolder; LCSC C17414
R13, R14: 3.3k; R_0805_2012Metric_Pad1.20x1.40mm_HandSolder; LCSC C26010
U1: IS32FL3237_DS; TQFP-48-1EP_7x7mm_P0.5mm_EP5x5mm_ThermalVias; LCSC C3189535
U2: AT90USB1287-A; TQFP-64_14x14mm_P0.8mm; LCSC C619282
Y2: 16 MHz; Crystal_SMD_TXC_7A-2Pin_5x3.2mm; LCSC C112572
baxlogo1: Baxlogo; baxlogo; not fitted

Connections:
+5V: C1.1, C2.1, C7.1, C8.1, C9.1, C10.1, C11.1, C12.1, C14.1, C15.1, C16.1, C17.1, C18.1, C19.1, D1.4 (A), D2.2 (A), D5.4 (A), D6.4 (A), D7.4 (A), D51.4 (A), D52.4 (A), D53.4 (A), D69.4 (A), D70.4 (VCC), D71.4 (VCC), D72.4 (VCC), D73.4 (VCC), D74.4 (VCC), D75.4 (VCC), D76.4 (VCC), D77.4 (VCC), D78.4 (VCC), D79.4 (VCC), D80.4 (VCC), D81.4 (VCC), D82.4 (VCC), D83.4 (VCC), D84.4 (VCC), J1.9, J2.1 (VBUS), J3.2, J4.4, J6.2, J7.3, R5.2, R13.2, R14.2, R15.2, R16.2, U1.41 (VCC), U2.3 (UVCC), U2.8 (VBUS), U2.21 (VCC), U2.52 (VCC), U2.64 (AVCC)
/AT90_RESET: J3.5, R5.1, U2.20 (~RESET)
/CAPSB: D1.3 (BK), D69.3 (BK), U1.22 (OUT21)
/CAPSG: D1.2 (GK), D69.2 (GK), U1.21 (OUT20)
/CAPSR: D1.1 (RK), D69.1 (RK), U1.20 (OUT19)
/D+: R3.1, U2.5 (D+)
/D++: J2.3 (D+), R3.2
/D-: R4.1, U2.4 (D-)
/D--: J2.2 (D-), R4.2
/DRVLED: J4.8, R9.2, R12.2, U2.60 (PF1)
/F1B: D5.3 (BK), U1.1 (OUT3)
/F1G: D5.2 (GK), U1.48 (OUT2)
/F1R: D5.1 (RK), U1.47 (OUT1)
/F2B: D6.3 (BK), U1.5 (OUT6)
/F2G: D6.2 (GK), U1.3 (OUT5)
/F2R: D6.1 (RK), U1.2 (OUT4)
/F3B: D7.3 (BK), U1.8 (OUT9)
/F3G: D7.2 (GK), U1.7 (OUT8)
/F3R: D7.1 (RK), U1.6 (OUT7)
/FLED: D4.1 (A1), R9.1
/IN_LED3: J5.1, R15.1, U2.59 (PF2)
/IN_LED4: J5.2, R16.1, U2.58 (PF3)
/KCLK: J4.1, J7.2, U2.27 (PD2)
/KDAT: J4.2, J7.1, U2.28 (PD3)
/LALT: J1.13, MX6.1 (COL), U2.15 (PB5)
/LAMI: J1.14, MX12.1 (COL), U2.16 (PB6)
/LSHIFT: J1.12, MX5.1 (COL), U2.14 (PB4)
/PLED: D3.1 (A1), R8.1
/PWRLED: J4.7, R6.1, R8.2, U2.61 (PF0)
/RSHFT: J1.6, MX68.1 (COL), U2.10 (PB0)
/RST_OUT: J4.3, U2.29 (PD4)
/SCL: J6.4, R13.1, U1.46 (SCL), U2.25 (PD0)
/SDA: J6.3, R14.1, U1.45 (SDA), U2.26 (PD1)
/SDB: C13.1, U1.39 (SDB), U2.30 (PD5)
/SPARE1: R10.2, U2.31 (PD6)
/SPARE2: R11.2, U2.32 (PD7)
/X2=7: J1.7, MX1.2 (ROW), MX7.2 (ROW), MX13.2 (ROW), MX18.2 (ROW), MX23.2 (ROW), MX28.2 (ROW), MX34.2 (ROW), MX39.2 (ROW), MX44.2 (ROW), MX49.2 (ROW), MX54.2 (ROW), MX77.2 (ROW), MX79.2 (ROW), MX84.2 (ROW), MX88.2 (ROW), U2.49 (PA2)
/X3=5: D22.1 (K), D54.1 (K), D55.1 (K), D56.1 (K), D57.1 (K), D58.1 (K), D59.1 (K), D60.1 (K), D61.1 (K), D62.1 (K), D63.1 (K), D64.1 (K), D65.1 (K), D66.1 (K), D67.1 (K), J1.5, U2.48 (PA3)
/X4=1: D21.1 (K), D37.1 (K), D38.1 (K), D39.1 (K), D40.1 (K), D41.1 (K), D42.1 (K), D43.1 (K), D44.1 (K), D45.1 (K), D46.1 (K), D47.1 (K), D48.1 (K), D49.1 (K), D50.1 (K), J1.1, U2.47 (PA4)
/X5=2: D20.1 (K), D24.1 (K), D25.1 (K), D26.1 (K), D27.1 (K), D28.1 (K), D29.1 (K), D30.1 (K), D31.1 (K), D32.1 (K), D33.1 (K), D34.1 (K), D35.1 (K), D36.1 (K), J1.2, MX73.2 (ROW), U2.46 (PA5)
/X6=3: D8.1 (K), D9.1 (K), D10.1 (K), D11.1 (K), D12.1 (K), D13.1 (K), D14.1 (K), D15.1 (K), D16.1 (K), D17.1 (K), D18.1 (K), D19.1 (K), D23.1 (K), D68.1 (K), J1.3, U2.45 (PA6)
/X7=4: J1.4, MX80.2 (ROW), MX81.2 (ROW), MX82.2 (ROW), MX83.2 (ROW), MX85.2 (ROW), MX86.2 (ROW), MX87.2 (ROW), MX89.2 (ROW), MX90.2 (ROW), MX91.2 (ROW), MX92.2 (ROW), MX93.2 (ROW), MX94.2 (ROW), MX95.2 (ROW), MX96.2 (ROW), U2.44 (PA7)
/Y0=29: J1.29, MX74.1 (COL), MX75.1 (COL), MX76.1 (COL), MX77.1 (COL), MX78.1 (COL), MX94.1 (COL), U2.35 (PC0)
/Y1=28: J1.28, MX54.1 (COL), MX69.1 (COL), MX71.1 (COL), MX72.1 (COL), MX73.1 (COL), MX83.1 (COL), U2.36 (PC1)
/Y2=27: J1.27, MX33.1 (COL), MX49.1 (COL), MX65.1 (COL), MX66.1 (COL), MX70.1 (COL), MX82.1 (COL), U2.37 (PC2)
/Y3=26: J1.26, MX44.1 (COL), MX60.1 (COL), MX61.1 (COL), MX67.1 (COL), MX81.1 (COL), U2.38 (PC3)
/Y4=25: J1.25, MX39.1 (COL), MX55.1 (COL), MX56.1 (COL), MX62.1 (COL), MX63.1 (COL), MX80.1 (COL), U2.39 (PC4)
/Y5=24: J1.24, MX50.1 (COL), MX51.1 (COL), MX57.1 (COL), MX58.1 (COL), MX88.1 (COL), MX96.1 (COL), U2.40 (PC5)
/Y6=23: J1.23, MX34.1 (COL), MX45.1 (COL), MX46.1 (COL), MX52.1 (COL), MX53.1 (COL), MX87.1 (COL), U2.41 (PC6)
/Y7=22: J1.22, MX40.1 (COL), MX41.1 (COL), MX47.1 (COL), MX48.1 (COL), MX84.1 (COL), MX86.1 (COL), U2.42 (PC7)
/Y8=21: J1.21, MX28.1 (COL), MX35.1 (COL), MX36.1 (COL), MX42.1 (COL), MX43.1 (COL), MX85.1 (COL), U2.33 (PE0)
/Y9=20: J1.20, MX23.1 (COL), MX29.1 (COL), MX30.1 (COL), MX37.1 (COL), MX38.1 (COL), MX92.1 (COL), U2.34 (PE1)
/Y10=19: J1.19, MX18.1 (COL), MX24.1 (COL), MX25.1 (COL), MX31.1 (COL), MX32.1 (COL), MX91.1 (COL), U2.43 (PE2/~HWB)
/Y11=18: J1.18, MX13.1 (COL), MX19.1 (COL), MX20.1 (COL), MX26.1 (COL), MX27.1 (COL), MX90.1 (COL), U2.9 (PE3)
/Y12=17: J1.17, MX7.1 (COL), MX14.1 (COL), MX15.1 (COL), MX21.1 (COL), MX22.1 (COL), MX89.1 (COL), U2.18 (PE4)
/Y13=16: J1.16, MX8.1 (COL), MX9.1 (COL), MX16.1 (COL), MX17.1 (COL), MX79.1 (COL), MX95.1 (COL), U2.19 (PE5)
/Y14=15: J1.15, MX1.1 (COL), MX2.1 (COL), MX3.1 (COL), MX10.1 (COL), MX11.1 (COL), MX93.1 (COL), U2.1 (PE6)
CAPS: R1.2, U2.17 (PB7)
CAPSLED: D2.1 (K), J1.31, R2.1
GND: C1.2, C2.2, C3.2, C4.1, C5.1, C6.1, C7.2, C8.2, C9.2, C10.2, C11.2, C12.2, C13.2, C14.2, C15.2, C16.2, C17.2, C18.2, C19.2, D3.4 (K2), D4.4 (K2), D70.3 (GND), D71.3 (GND), D72.3 (GND), D73.3 (GND), D74.3 (GND), D75.3 (GND), D76.3 (GND), D77.3 (GND), D78.3 (GND), D79.3 (GND), D80.3 (GND), D81.3 (GND), D82.3 (GND), D83.3 (GND), D84.3 (GND), H24.1, J1.30, J2.5 (GND), J2.6 (Shield), J3.6, J4.6, J6.1, J7.4, MX4.2 (ROW), MX5.2 (ROW), MX6.2 (ROW), MX12.2 (ROW), MX59.2 (ROW), MX64.2 (ROW), MX68.2 (ROW), Q1.2 (E), R6.2, R7.1, R10.1, R11.1, R12.1, U1.4 (GND), U1.18 (GND), U1.19 (GND), U1.33 (GND), U1.40 (AD), U1.42 (GND), U1.43 (GND), U1.49 (GND), U2.6 (UGND), U2.22 (GND), U2.53 (GND), U2.63 (GND)
MISO: J1.11, J3.1, MX4.1 (COL), U2.13 (PB3)
MOSI: J1.10, J3.4, MX59.1 (COL), U2.12 (PB2)
unnamed: C3.1, U2.24 (XTAL1), Y2.1
unnamed: C4.2, U2.23 (XTAL2), Y2.2
unnamed: C5.2, U2.7 (UCAP)
unnamed: C6.2, U2.62 (AREF)
unnamed: D3.2 (K1), D3.3 (A2)
unnamed: D4.2 (K1), D4.3 (A2)
unnamed: D8.2 (A), MX11.2 (ROW)
unnamed: D9.2 (A), MX17.2 (ROW)
unnamed: D10.2 (A), MX22.2 (ROW)
unnamed: D11.2 (A), MX27.2 (ROW)
unnamed: D12.2 (A), MX32.2 (ROW)
unnamed: D13.2 (A), MX33.2 (ROW)
unnamed: D14.2 (A), MX38.2 (ROW)
unnamed: D15.2 (A), MX43.2 (ROW)
unnamed: D16.2 (A), MX48.2 (ROW)
unnamed: D17.2 (A), MX53.2 (ROW)
unnamed: D18.2 (A), MX58.2 (ROW)
unnamed: D19.2 (A), MX63.2 (ROW)
unnamed: D20.2 (A), MX78.2 (ROW)
unnamed: D21.2 (A), MX74.2 (ROW)
unnamed: D22.2 (A), MX75.2 (ROW)
unnamed: D23.2 (A), MX76.2 (ROW)
unnamed: D24.2 (A), MX10.2 (ROW)
unnamed: D25.2 (A), MX16.2 (ROW)
unnamed: D26.2 (A), MX21.2 (ROW)
unnamed: D27.2 (A), MX26.2 (ROW)
unnamed: D28.2 (A), MX31.2 (ROW)
unnamed: D29.2 (A), MX37.2 (ROW)
unnamed: D30.2 (A), MX42.2 (ROW)
unnamed: D31.2 (A), MX47.2 (ROW)
unnamed: D32.2 (A), MX52.2 (ROW)
unnamed: D33.2 (A), MX57.2 (ROW)
unnamed: D34.2 (A), MX62.2 (ROW)
unnamed: D35.2 (A), MX67.2 (ROW)
unnamed: D36.2 (A), MX70.2 (ROW)
unnamed: D37.2 (A), MX3.2 (ROW)
unnamed: D38.2 (A), MX9.2 (ROW)
unnamed: D39.2 (A), MX15.2 (ROW)
unnamed: D40.2 (A), MX20.2 (ROW)
unnamed: D41.2 (A), MX25.2 (ROW)
unnamed: D42.2 (A), MX30.2 (ROW)
unnamed: D43.2 (A), MX36.2 (ROW)
unnamed: D44.2 (A), MX41.2 (ROW)
unnamed: D45.2 (A), MX46.2 (ROW)
unnamed: D46.2 (A), MX51.2 (ROW)
unnamed: D47.2 (A), MX56.2 (ROW)
unnamed: D48.2 (A), MX61.2 (ROW)
unnamed: D49.2 (A), MX66.2 (ROW)
unnamed: D50.2 (A), MX71.2 (ROW)
unnamed: D51.1 (RK), U1.9 (OUT10)
unnamed: D51.2 (GK), U1.10 (OUT11)
unnamed: D51.3 (BK), U1.11 (OUT12)
unnamed: D52.1 (RK), U1.12 (OUT13)
unnamed: D52.2 (GK), U1.13 (OUT14)
unnamed: D52.3 (BK), U1.14 (OUT15)
unnamed: D53.1 (RK), U1.15 (OUT16)
unnamed: D53.2 (GK), U1.16 (OUT17)
unnamed: D53.3 (BK), U1.17 (OUT18)
unnamed: D54.2 (A), MX2.2 (ROW)
unnamed: D55.2 (A), MX8.2 (ROW)
unnamed: D56.2 (A), MX14.2 (ROW)
unnamed: D57.2 (A), MX19.2 (ROW)
unnamed: D58.2 (A), MX24.2 (ROW)
unnamed: D59.2 (A), MX29.2 (ROW)
unnamed: D60.2 (A), MX35.2 (ROW)
unnamed: D61.2 (A), MX40.2 (ROW)
unnamed: D62.2 (A), MX45.2 (ROW)
unnamed: D63.2 (A), MX50.2 (ROW)
unnamed: D64.2 (A), MX55.2 (ROW)
unnamed: D65.2 (A), MX60.2 (ROW)
unnamed: D66.2 (A), MX65.2 (ROW)
unnamed: D67.2 (A), MX69.2 (ROW)
unnamed: D68.2 (A), MX72.2 (ROW)
unnamed: D70.5 (CO), D71.2 (CI)
unnamed: D70.6 (DO), D71.1 (DI)
unnamed: D71.5 (CO), D72.2 (CI)
unnamed: D71.6 (DO), D72.1 (DI)
unnamed: D72.5 (CO), D73.2 (CI)
unnamed: D72.6 (DO), D73.1 (DI)
unnamed: D73.5 (CO), D74.2 (CI)
unnamed: D73.6 (DO), D74.1 (DI)
unnamed: D74.5 (CO), D75.2 (CI)
unnamed: D74.6 (DO), D75.1 (DI)
unnamed: D75.5 (CO), D76.2 (CI)
unnamed: D75.6 (DO), D76.1 (DI)
unnamed: D76.5 (CO), D77.2 (CI)
unnamed: D76.6 (DO), D77.1 (DI)
unnamed: D77.5 (CO), D78.2 (CI)
unnamed: D77.6 (DO), D78.1 (DI)
unnamed: D78.5 (CO), D79.2 (CI)
unnamed: D78.6 (DO), D79.1 (DI)
unnamed: D79.5 (CO), D80.2 (CI)
unnamed: D79.6 (DO), D80.1 (DI)
unnamed: D80.5 (CO), D81.2 (CI)
unnamed: D80.6 (DO), D81.1 (DI)
unnamed: D81.5 (CO), D82.2 (CI)
unnamed: D81.6 (DO), D82.1 (DI)
unnamed: D82.5 (CO), D83.2 (CI)
unnamed: D82.6 (DO), D83.1 (DI)
unnamed: D83.5 (CO), D84.2 (CI)
unnamed: D83.6 (DO), D84.1 (DI)
unnamed: Q1.1 (B), R1.1
unnamed: Q1.3 (C), R2.2
unnamed: R7.2, U1.44 (ISET)
unnamed: D70.2 (CI), U2.50 (PA1)
unnamed: D70.1 (DI), U2.51 (PA0)
SCLK: J1.8, J3.3, MX64.1 (COL), U2.11 (PB1)

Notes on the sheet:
Populate R6 only if classic A500 power LED is not connected
Populate either D1 or D69
TODO: - shorten by 1mm on the right side of the PCB (DONE) - Pull-Down for DRVLED (1k) (DONE) - Pull-Up for IN_LED3, IN_LED4 (10k) (DONE) - Pull-Up for SCL,SDA (DONE) - R7: 3.9k Resistor for LED driver (was: 3.3k) (DONE) - Turn Diodes around (DONE) - Bax Logo :-) (done) - Spacebar retention update 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
R10 disables D2 (classic CAPS Led)
R11 enables Digital RGB LEDs (D70-D84)

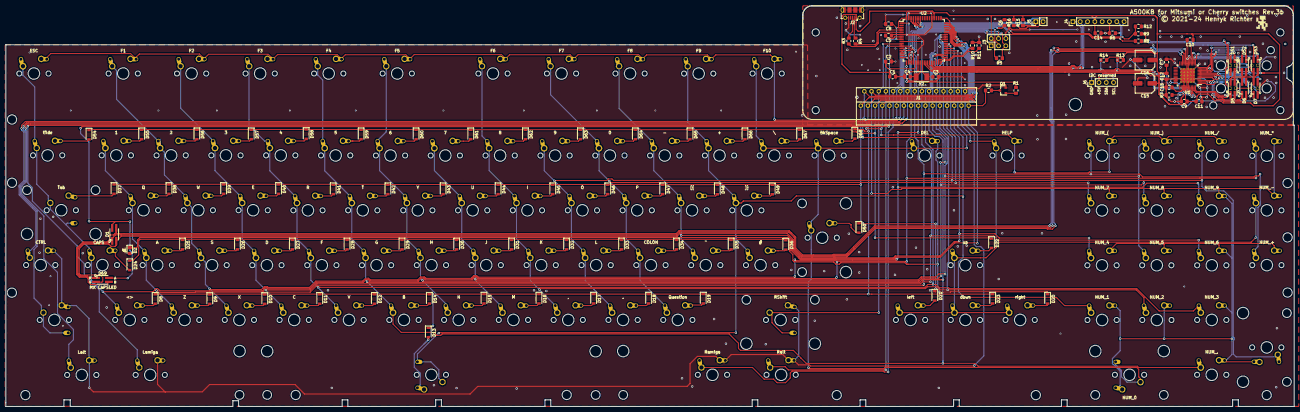
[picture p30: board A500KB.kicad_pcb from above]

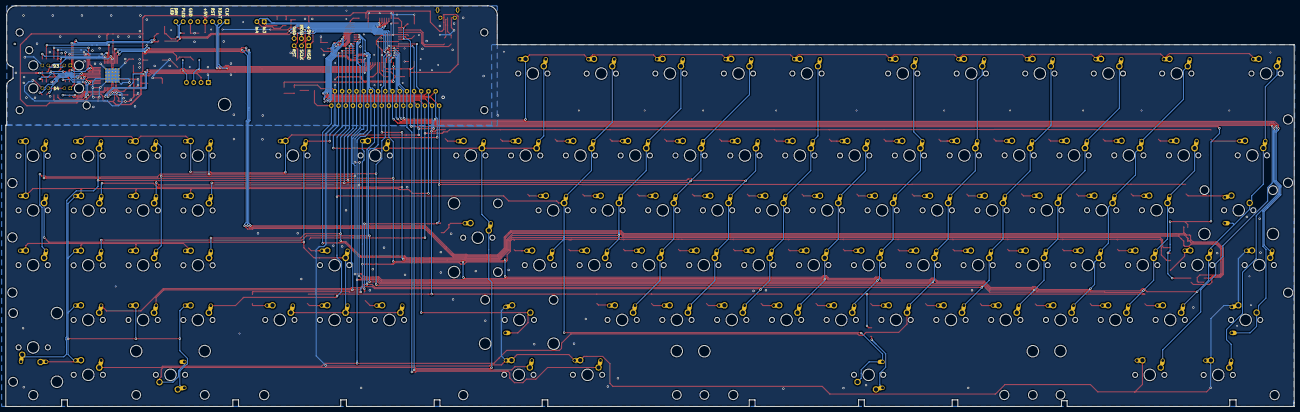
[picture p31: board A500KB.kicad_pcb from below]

Board: 2 copper layers, 447.8 x 139.2 mm, 230 parts (2 on the bottom side), 139 nets.

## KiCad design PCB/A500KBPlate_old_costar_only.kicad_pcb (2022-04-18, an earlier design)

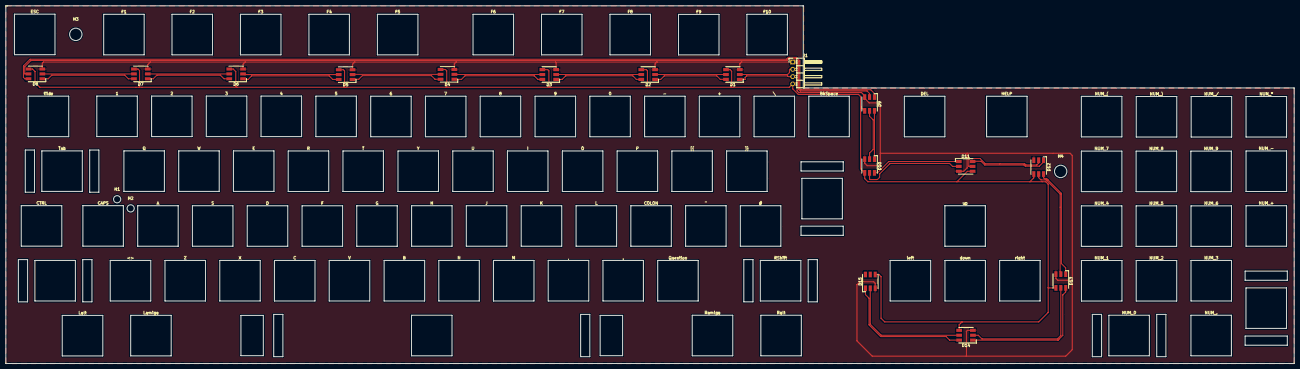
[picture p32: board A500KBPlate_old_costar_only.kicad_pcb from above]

Board: 2 copper layers, 448.3 x 124.5 mm, 116 parts (0 on the bottom side), 32 nets.

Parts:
D1, D2, D3, D4, D5, D6, D7, D8, D9, D10, D11, D12, D13, D14, D15: APA102; LED_RGB_5050-6
H1, H2: MountingHole; MountingHole_2.5mm
H3, H4: MountingHole; MountingHole_4.3mm_M4
J1: Conn_01x04; PinHeader_1x04_P2.54mm_Horizontal
MX1: ESC; MXMitsumi-1U-PlateCutout
MX2: tilde; MXMitsumi-1.5U-PlateCutout
MX3: Tab; MXMitsumi-2U-PlateCutout
MX4: CTRL; MXMitsumi-1.25U-PlateCutout
MX5: LShift; MXMitsumi-1.75U-PlateCutout
MX6: Lalt; MXMitsumi-1.25U-PlateCutout
MX7: F1; MXMitsumi-1.25U-PlateCutout
MX8: 1; MXMitsumi-1U-PlateCutout
MX9: Q; MXMitsumi-1U-PlateCutout
MX10: CAPS; MXMitsumi-1U-PlateCutout
MX11: <>; MXMitsumi-1U-PlateCutout
MX12: Lamiga; MXMitsumi-1.25U-PlateCutout
MX13: F2; MXMitsumi-1.25U-PlateCutout
MX14: 2; MXMitsumi-1U-PlateCutout
MX15: W; MXMitsumi-1U-PlateCutout
MX16: A; MXMitsumi-1U-PlateCutout
MX17: Z; MXMitsumi-1U-PlateCutout
MX18: F3; MXMitsumi-1.25U-PlateCutout
MX19: 3; MXMitsumi-1U-PlateCutout
MX20: E; MXMitsumi-1U-PlateCutout
MX21: S; MXMitsumi-1U-PlateCutout
MX22: X; MXMitsumi-1U-PlateCutout
MX23: F4; MXMitsumi-1.25U-PlateCutout
MX24: 4; MXMitsumi-1U-PlateCutout
MX25: R; MXMitsumi-1U-PlateCutout
MX26: D; MXMitsumi-1U-PlateCutout
MX27: C; MXMitsumi-1U-PlateCutout
MX28: F5; MXMitsumi-1.25U-PlateCutout
MX29: 5; MXMitsumi-1U-PlateCutout
MX30: T; MXMitsumi-1U-PlateCutout
MX31: F; MXMitsumi-1U-PlateCutout
MX32: V; MXMitsumi-1U-PlateCutout
MX33: Space; MXMitsumi-9U-PlateCutout
MX34: F6; MXMitsumi-1.25U-PlateCutout
MX35: 6; MXMitsumi-1U-PlateCutout
MX36: Y; MXMitsumi-1U-PlateCutout
MX37: G; MXMitsumi-1U-PlateCutout
MX38: B; MXMitsumi-1U-PlateCutout
MX39: F7; MXMitsumi-1.25U-PlateCutout
MX40: 7; MXMitsumi-1U-PlateCutout
MX41: U; MXMitsumi-1U-PlateCutout
MX42: H; MXMitsumi-1U-PlateCutout
MX43: N; MXMitsumi-1U-PlateCutout
MX44: F8; MXMitsumi-1.25U-PlateCutout
MX45: 8; MXMitsumi-1U-PlateCutout
MX46: I; MXMitsumi-1U-PlateCutout
MX47: J; MXMitsumi-1U-PlateCutout
MX48: M; MXMitsumi-1U-PlateCutout
MX49: F9; MXMitsumi-1.25U-PlateCutout
MX50: 9; MXMitsumi-1U-PlateCutout
MX51: O; MXMitsumi-1U-PlateCutout
MX52: K; MXMitsumi-1U-PlateCutout
MX53: ,; MXMitsumi-1U-PlateCutout
MX54: F10; MXMitsumi-1.25U-PlateCutout
MX55: 0; MXMitsumi-1U-PlateCutout
MX56: P; MXMitsumi-1U-PlateCutout
MX57: L; MXMitsumi-1U-PlateCutout
MX58: .; MXMitsumi-1U-PlateCutout
MX59: Ramiga; MXMitsumi-1.25U-PlateCutout
MX60: -; MXMitsumi-1U-PlateCutout
MX61: [{; MXMitsumi-1U-PlateCutout
MX62: COLON; MXMitsumi-1U-PlateCutout
MX63: Question; MXMitsumi-1U-PlateCutout
MX64: Ralt; MXMitsumi-1.25U-PlateCutout
MX65: +; MXMitsumi-1U-PlateCutout
MX66: ]}; MXMitsumi-1U-PlateCutout
MX67: "; MXMitsumi-1U-PlateCutout
MX68: RShift; MXMitsumi-2.75U-PlateCutout
MX69: \; MXMitsumi-1U-PlateCutout
MX70: #; MXMitsumi-1U-PlateCutout
MX71: Return; MXMitsumi-ISO-PlateCutout
MX72: BkSpace; MXMitsumi-1U-PlateCutout
MX73: DEL; MXMitsumi-1.5U-PlateCutout
MX74: left; MXMitsumi-1U-PlateCutout
MX75: up; MXMitsumi-1U-PlateCutout
MX76: down; MXMitsumi-1U-PlateCutout
MX77: HELP; MXMitsumi-1.5U-PlateCutout
MX78: right; MXMitsumi-1U-PlateCutout
MX79: NUM_(; MXMitsumi-1U-PlateCutout
MX80: NUM_7; MXMitsumi-1U-PlateCutout
MX81: NUM_4; MXMitsumi-1U-PlateCutout
MX82: NUM_1; MXMitsumi-1U-PlateCutout
MX83: NUM_0; MXMitsumi-2U-PlateCutout
MX84: NUM_); MXMitsumi-1U-PlateCutout
MX85: NUM_8; MXMitsumi-1U-PlateCutout
MX86: NUM_5; MXMitsumi-1U-PlateCutout
MX87: NUM_2; MXMitsumi-1U-PlateCutout
MX88: NUM_/; MXMitsumi-1U-PlateCutout
MX89: NUM_9; MXMitsumi-1U-PlateCutout
MX90: NUM_6; MXMitsumi-1U-PlateCutout
MX91: NUM_3; MXMitsumi-1U-PlateCutout
MX92: NUM_.; MXMitsumi-1U-PlateCutout
MX93: NUM_*; MXMitsumi-1U-PlateCutout
MX94: NUM_-; MXMitsumi-1U-PlateCutout
MX95: NUM_+; MXMitsumi-1U-PlateCutout
MX96: NUM_ENTER; MXMitsumi-2U-VerticalStabilizers-PlateCutout

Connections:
/+5V: D1.4, D2.4, D3.4, D4.4, D5.4, D6.4, D7.4, D8.4, D9.4, D10.4, D11.4, D12.4, D13.4, D14.4, D15.4, J1.4
/CLK: D1.2, J1.2
/DAT: D1.1, J1.3
/GND: D1.3, D2.3, D3.3, D4.3, D5.3, D6.3, D7.3, D8.3, D9.3, D10.3, D11.3, D12.3, D13.3, D14.3, D15.3, J1.1
unnamed: D1.5, D2.2
unnamed: D1.6, D2.1
unnamed: D2.5, D3.2
unnamed: D2.6, D3.1
unnamed: D3.5, D4.2
unnamed: D3.6, D4.1
unnamed: D4.5, D5.2
unnamed: D4.6, D5.1
unnamed: D5.5, D6.2
unnamed: D5.6, D6.1
unnamed: D6.5, D7.2
unnamed: D6.6, D7.1
unnamed: D7.5, D8.2
unnamed: D7.6, D8.1
unnamed: D8.5, D9.2
unnamed: D8.6, D9.1
unnamed: D9.6, D10.1
unnamed: D9.5, D10.2
unnamed: D10.5, D11.2
unnamed: D10.6, D11.1
unnamed: D11.5, D12.2
unnamed: D11.6, D12.1
unnamed: D12.5, D13.2
unnamed: D12.6, D13.1
unnamed: D13.5, D14.2
unnamed: D13.6, D14.1
unnamed: D14.5, D15.2
unnamed: D14.6, D15.1

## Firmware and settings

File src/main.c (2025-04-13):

/*
 ********************************************************************************
 * main.c                                                                       *
 *                                                                              *
 * Author: Henryk Richter <bax@comlab.uni-rostock.de>                           *
 *                                                                              *
 * Purpose: Amiga keyboard based on ATMega32                                    *
 *                                                                              *
 * DEBUG NOTES: RXD (D2) / TXD (D3) are the same pins used for KBClock (D2) and *
 *              KBData (D3)                                                     *
 * Hence, if DEBUG is defined (see Makefile), then KBClock goes to F2 and       *
 *        KBData to F3, i.e. IN_LED3,IN_LED4                                    *
 *                                                                              *
 *                                                                              *
 *                                                                              *
 *                                                                              *
 ********************************************************************************
*/
#define ENABLE_WATCHDOG WDTO_250MS
#define ENABLE_USB
#include <avr/interrupt.h>
#include <avr/pgmspace.h>
#include <avr/io.h>
#include <util/delay.h> /* might be <avr/delay.h>, depending on toolchain */
#ifdef ENABLE_WATCHDOG
#include <avr/wdt.h>
#endif
//#include "avr/delay.h"
#include "baxtypes.h"
#include "twi.h"
#include "led.h"
#include "spi.h"
#include "led_digital.h"
#ifdef ENABLE_USB
#include "usb.h"
#endif /* ENABLE_USB */

#include "kbdefs.h"

//#define DEBUGONLY
#ifdef DEBUG
#include "uart.h"
#define DBGOUT(a) uart1_putc(a);
#define DEBUG_ON()
#else
#define DBGOUT(a)
#define DEBUG_ON()
#endif

#define NULL (0)

/* set/clear Bit in register or port */
#define BitSet( _port_, _bit_ ) _port_ |=   (1 << (_bit_) )
#define BitClr( _port_, _bit_ ) _port_ &= (~(1 << (_bit_) ) )
/* copy bit from source to destination (2 clocks via T Bit) */
#define BitCpy( _out_, _obit_, _in_, _ibit_ ) \
	asm volatile ( "bst %2,%3" "\n\t" \
	               "bld %0,%1" : "+r" (_out_) : "I" (_obit_) , "r" (_in_) , "I" (_ibit_) );


/* internal proto */
char amiga_kbsend( unsigned char scan_internal, unsigned char updown );
char amiga_kbsync( void );

/* ringbuffer defs and protos */
typedef unsigned char RING_TYPE;
typedef unsigned char RINGPOS_TYPE;
void init_ring( void );
char write_ring( RING_TYPE val );
char read_ring( RING_TYPE *val );

/* put number on UART */
void uart_puthexuchar(unsigned char a);
void uart_puthexuint(uint16_t a);

/* regular caps on/off = 1/0, with force flag 0x40 */
void show_caps( unsigned char state );


unsigned char *recv_commands(unsigned char *nrecv);


/* active key table -> bytes here, could be mapped to bits */
unsigned char kbtable[(OCOUNT+OCOUNT_SPC)*ICOUNT];

/* commands from Amiga, USB LED configuration */
#define RECVBUFSIZE 32 
unsigned char recv_buffer[RECVBUFSIZE];

#define KEYIDLE 0 /* keyidle / keydown should only use one bit (!) */
#define KEYDOWN 1
#define DEBOUNCE_TIME  32  /* 0...127 -> number of iterations to wait for key to settle */
#define DEBOUNCE_SHIFT   1 /* debounce count is shifted by this in kbtable              */
#define DEBOUNCE_MASK  127 /* mask to fetch debounce count                              */

#define GETKEYSTATE(_a_) kbtable[_a_]
#define SETKEYSTATE(_a_,_b_) kbtable[_a_] = _b_



/* port mapping, base ADDRESS is port D */
#define PDOFF 0x0
#define PAOFF _SFR_ADDR(DDRA)-_SFR_ADDR(DDRD)
#define PBOFF _SFR_ADDR(DDRB)-_SFR_ADDR(DDRD)
#define PCOFF _SFR_ADDR(DDRC)-_SFR_ADDR(DDRD)
#define PEOFF _SFR_ADDR(DDRE)-_SFR_ADDR(DDRD)


/* states */
#define STATE_RESYNC	1	/* sync loss */
#define STATE_POWERUP	2	/* after powerup or reset */
#define STATE_RESET	4	/* sent reset warning */
#define STATE_KBWAIT	8	/* wait for KB ACK low */
#define STATE_KBWAIT2	16	/* wait for KB ACK high (after low) */
#define STATE_POWERUP2	32	/* remember that we have to send end of powerup sequence */
#define STATE_OVERFLOW	64	/* buffer overflow */

/* waiting time for sync (in 10 us units) = 143000 us = 143 ms */
#define SYNC_WAIT	14300
/* waiting time for reset (in 10 us units) = 10ms+500ms */
#define RESET_WAIT	60000
/* waiting time before rest is issued */
#define RESET_WAIT1	20

/* delay in loops switching between send/receive modes */
#define KBDSEND_SWITCHDELAY 4
/* delay in loops after a key was acknowledged by remote end */
#define KBDSEND_KEYDELAY    2

/* map row/column to scan code, each start with 1 (labeling on board) */
#define SCANCODE(_row_,_column_) (((_row_)-1)*ICOUNT) + (_column_)-1

/* keyboard input table (kbinputlist is 0 terminated) */
                                 /* 1     2     3     4     5     6     7     8     9     10    11    12    13      */
//unsigned char  kbinputlist[14] =  { 1<<5, 1<<6, 1<<6, 1<<3, 1<<4, 1<<2, 1<<3, 1<<7, 1<<4, 1<<5, 1<<0, 1<<1, 1<<2,  0 };
//unsigned short kbinputports[14] = { PDOFF,PDOFF,PCOFF,PDOFF,PDOFF,PDOFF,PCOFF,PDOFF,PCOFF,PCOFF,PCOFF,PCOFF,PCOFF, 0 };

unsigned char kbinputlist[16]  = { 1<<0, 1<<1, 1<<2, 1<<3, 1<<4, 1<<5, 1<<6, 1<<7, 1<<0, 1<<1, 1<<2, 1<<3, 1<<4, 1<<5, 1<<6 ,0};
unsigned short kbinputports[16]= { PCOFF,PCOFF,PCOFF,PCOFF,PCOFF,PCOFF,PCOFF,PCOFF,PEOFF,PEOFF,PEOFF,PEOFF,PEOFF,PEOFF,PEOFF,0};

//unsigned char kbinputlist[14] =  { 0xFC,   0x7F,  0 };
//unsigned char kbinputports[14] = { PORTDOFF,  PORTCOFF, 0 };

/* mapping from our keyboard layout to Amiga scan codes */
/* 
   The last row are the special keys which are scanned key by key, beginning with
   scancode 7,1. Please note that the order of keys in the last row needs to 
   match the order in "kbinputspecials".

   scan codes 0x47-0x49,0x68-0x7F are unused
*/
const unsigned char kbmap[(OCOUNT+OCOUNT_SPC)*ICOUNT] PROGMEM = {
/*help F10  F9   F8   F7   KP/  F6   KP]  F5   F4   F3   F2   F1   KP[  ESC  */
  0x5f,0x59,0x58,0x57,0x56,0x5c,0x55,0x5b,0x54,0x53,0x52,0x51,0x50,0x5a,0x45,
/*cu   \    +-   -_   0    9    8    7    6    5    4    3    2    1    '    */
  0x4c,0x0d,0x0C,0x0B,0x0A,0x09,0x08,0x07,0x06,0x05,0x04,0x03,0x02,0x01,0x00,
/*cl   Ret  ]}   [{   P    O    I    U    Y    T    R    E    W    Q    Tab  */
  0x4f,0x44,0x1B,0x1A,0x19,0x18,0x17,0x16,0x15,0x14,0x13,0x12,0x11,0x10,0x42,
/*cr   Del  #    .,   ;:   L    K    J    H    G    F    D    S    A    Caps */
  0x4e,0x46,0x2B,0x2A,0x29,0x28,0x27,0x26,0x25,0x24,0x23,0x22,0x21,0x20,0x62,
/*cd   BKSpC SPC N/A  /?   .>   ,<   M    N    B    V    C    X    Z    <>   */
  0x4d,0x41,0x40,0x40,0x3A,0x39,0x38,0x37,0x36,0x35,0x34,0x33,0x32,0x31,0x30,
/*Num- Num0 Num1 Num4 Num7 KPENTNum2 Num5 Num8 Num. Num3 Num6 Num9 Num+ Num* */
  0x4a,0x0F,0x1D,0x2D,0x3D,0x43,0x1E,0x2E,0x3E,0x3C,0x1F,0x2F,0x3F,0x5E,0x5D,
/* LA  LALT LSH  CTRL RA   RALT RSHIFT                                       */
  0x66,0x64,0x60,0x63,0x67,0x65,0x61
};
unsigned char kbinputspecials[8]  = { 1<<SPCB_LAMIGA, 1<<SPCB_LALT,1<<SPCB_LSHIFT,1<<SPCB_CTRL,
                                      1<<SPCB_RAMIGA, 1<<SPCB_RALT,1<<SPCB_RSHIFT,0};

#define D70 0x00
#define D71 0x01
#define D72 0x02
#define D73 0x03
#define D74 0x04
#define D75 0x05
#define D76 0x06
#define D77 0x07
#define D78 0x08
#define D79 0x09
#define D80 0x0A
#define D81 0x0B
#define D82 0x0C
#define D83 0x0D
#define D84 0x0E
#define D8INVAL 0x0f
/*
 map denoting how far left/right a pressed key is in the layout

 15 LEDs, where D70-D81 are more or less in a row (left-to-right), while 
 D82,D83,D84 are below them and go leftward

 0x00 0x01 0x02 0x03 0x04 0x05 0x06 0x07 0x08 0x09 0x0a 0x0b 0x0c 0x0d 0x0e 
 D70  D71  D72  D73  D74  D75  D76  D77  D78  D79  D80  D81  D82  D83  D84 

 L-R are indices 0-9, i.e ESC-F10

 right now, all keys are marked with something, see D8INVAL if necessary
 to denote an invalid key

*/
const unsigned char kbleftright[(OCOUNT+OCOUNT_SPC)*ICOUNT] PROGMEM = {
/*help F10  F9   F8   F7   KP/  F6   KP]  F5   F4   F3   F2   F1   KP[  ESC  */
   D81, D78, D77, D76, D76, D81, D75, D81, D74, D73, D72, D72, D71, D81, D70,
/*cu   \    +-   -_   0    9    8    7    6    5    4    3    2    1    '    */
   D80, D78, D77, D77, D76, D76, D75, D75, D74, D73, D73, D72, D72, D71, D70,
/*cl   Ret  ]}   [{   P    O    I    U    Y    T    R    E    W    Q    Tab  */
   D84, D79, D78, D77, D77, D76, D75, D75, D74, D74, D73, D72, D72, D71, D70,
/*cr   Del  #    .,   ;:   L    K    J    H    G    F    D    S    A    Caps */
   D82, D79, D78, D77, D77, D76, D76, D75, D74, D74, D73, D73, D72, D71, D70,
/*cd   BKSpC SPC N/A  /?   .>   ,<   M    N    B    V    C    X    Z    <>   */
   D83, D79, D74, D84, D77, D77, D77, D75, D75, D74, D74, D73, D72, D72, D71,
/*Num- Num0 Num1 Num4 Num7 KPENTNum2 Num5 Num8 Num. Num3 Num6 Num9 Num+ Num* */
   D81, D82, D82, D82, D81, D82, D82, D82, D81, D82, D82, D82, D81, D82, D81,
/* LA  LALT LSH  CTRL RA   RALT RSHIFT                                       */
   D70, D71, D70, D70, D78, D78, D84
};


#ifdef ENABLE_USB
/* mapping from our keyboard layout to USB HID scan codes */
/* 
   The last row are the special keys which are scanned key by key, beginning with
   scancode 7,1. Please note that the order of keys in the last row needs to 
   match the order in "kbinputspecials".

   scan codes 0x47-0x49,0x68-0x7F are unused

   KEY_HASHTILDE 0x32 	Keyboard Int' # and ~ 	Intended for key next to vertical Return key. Keyboard Backslash (0x31) is used instead
   \ KEY_BACKSLASH needs update
*/
#include "usb_keys.h"
const unsigned char usbkbmap[(OCOUNT+OCOUNT_SPC)*ICOUNT] PROGMEM = {
/* help      F10       F9      F8      F7      KP/          F6      KP]   F5     F4     F3     F2     F1      KP[   ESC  */
 KEY_HELP, KEY_F10,  KEY_F9, KEY_F8, KEY_F7, KEY_KPSLASH, KEY_F6, KEY_SCROLLLOCK, KEY_F5,KEY_F4,KEY_F3,KEY_F2,KEY_F1, KEY_NUMLOCK,  KEY_ESC, 
/*   KEY_HELP, KEY_F10,  KEY_F9, KEY_F8, KEY_F7, KEY_KPSLASH, KEY_F6, KEY_KPRBRACE,   KEY_F5,KEY_F4,KEY_F3,KEY_F2,KEY_F1, KEY_KPLBRACE, KEY_ESC,*/
/*cu        \             +-         -_         0     9     8     7     6     5     4     3     2     1     '~          */
  KEY_UP,   KEY_BACKSLASH,KEY_EQUAL, KEY_MINUS, KEY_0,KEY_9,KEY_8,KEY_7,KEY_6,KEY_5,KEY_4,KEY_3,KEY_2,KEY_1,KEY_GRAVE,
/*cl        Ret       ]}              [{             P     O     I     U     Y     T     R     E     W     Q     Tab  */
  KEY_LEFT, KEY_ENTER,KEY_RIGHTBRACE, KEY_LEFTBRACE, KEY_P,KEY_O,KEY_I,KEY_U,KEY_Y,KEY_T,KEY_R,KEY_E,KEY_W,KEY_Q,KEY_TAB,
/*cr        Del        #              '"              ;:             L     K     J     H     G     F     D     S     A     Caps */
  KEY_RIGHT,KEY_DELETE,KEY_HASHTILDE, KEY_APOSTROPHE, KEY_SEMICOLON, KEY_L,KEY_K,KEY_J,KEY_H,KEY_G,KEY_F,KEY_D,KEY_S,KEY_A,KEY_CAPSLOCK,
/*cd        BKSpC         SPC        N/A      /?         .>       ,<         M     N     B     V     C     X     Z     <>   */
  KEY_DOWN, KEY_BACKSPACE,KEY_SPACE, KEY_DOT, KEY_SLASH, KEY_DOT, KEY_COMMA, KEY_M,KEY_N,KEY_B,KEY_V,KEY_C,KEY_X,KEY_Z,KEY_102ND, /* 102ND is between Shift and Z */
/*Num-      Num0  Num1  Num4  Num7  KPENT Num2  Num5  Num8  Num.  Num3  Num6  Num9  Num+  Num* */
KEY_KPMINUS,KEY_KP0, KEY_KP1, KEY_KP4, KEY_KP7, KEY_KPENTER, KEY_KP2, KEY_KP5, KEY_KP8, KEY_KPDOT, KEY_KP3, KEY_KP6, KEY_KP9, KEY_KPPLUS, KEY_KPASTERISK,
/* separate row, handled differently (part of the modifiers, not the sent keys */
/* LA  LALT LSH  CTRL RA   RALT RSHIFT                                       */
  KEY_MOD_LMETA,KEY_MOD_LALT,KEY_MOD_LSHIFT,KEY_MOD_LCTRL,KEY_MOD_RMETA,KEY_MOD_RALT,KEY_MOD_RSHIFT
};
#endif /* ENABLE_USB */

#define COMM_ACK   0x73
#define COMM_ACK1  0x7B
#define COMM_NACK  0x77
#define COMM_NACK1 0x7F

#if 0
/* ~  1    ESC  F1   F2   F3   F4   F5   F6   F7   F8   F9   F10    */
 0x00,0x01,0x45,0x50,0x51,0x52,0x53,0x54,0x55,0x56,0x57,0x58,0x59,
/* 2  3    4    5    6    7    8    9    0    ß    ´    \    BKSPC  */
 0x02,0x03,0x04,0x05,0x06,0x07,0x08,0x09,0x0a,0x0b,0x0c,0x0d,0x41,
/*TAB 'q', 'w', 'e', 'r', 't', 'z', 'u', 'i', 'o', 'p', 'ü', '+',   */
 0x42,0x10,0x11,0x12,0x13,0x14,0x15,0x16,0x17,0x18,0x19,0x1a,0x1b,
/*CTRL CAPS, a  s    d    f    g    h    j    k    l    ö    ä      */
 0x63,0x62,0x20,0x21,0x22,0x23,0x24,0x25,0x26,0x27,0x28,0x29,0x2a,
/* Sh  <   y    x    c    v    b    n    m    ,    .    -     Shift */ 
 0x60,0x30,0x31,0x32,0x33,0x34,0x35,0x36,0x37,0x38,0x39,0x3a,0x61,
/*ALT AMIGA  xx   xx   xx   xx SPACE  xx  xx Amiga Alt  #   Return  */
 0x64,0x66,0x5d,0x5d,0x5d,0x5d,0x40,0x5d,0x5d,0x67,0x64,0x2b,0x44,
/* KP. KP0 xx,  KP1  KP2  KP3  KPEnt  cd   cl   cr   cu help del    */
 0x3c,0x0f,0x5d,0x1d,0x1e,0x1f,0x43,0x4d,0x4f,0x4e,0x4c,0x5f,0x46,
/*KP] KP[  KP/  KP4  KP5  KP6  xx   KP+  KP-  KP*  KP9  KP8  KP7   */
 0x5b,0x5a,0x5c,0x2d,0x2e,0x2f,0x5d,0x5e,0x4a,0x5d,0x3f,0x3e,0x3d,
};
#endif

/* Amiga Keycodes */
#define KEYCODE_RESET_WARN		0x78
#define KEYCODE_RETRANSMIT		0xf9
#define KEYCODE_BUFFER_OVERFLOW		0xfa
#define KEYCODE_KEYBOARD_FAIL		0xfc
#define KEYCODE_POWERUPSTREAM_START	0xfd
#define KEYCODE_POWERUPSTREAM_STOP	0xfe

/* LAMIGA R5 C1 RAMIGA R5 C9 CTRL R3 C0 */
#define SCANCODE_LAMIGA   SCANCODE(7,1)
#define SCANCODE_RAMIGA   SCANCODE(7,5)
#define SCANCODE_CTRL     SCANCODE(7,4)
#define SCANCODE_CAPSLOCK SCANCODE(4,15)

/* ringbuffer for sending */
#define SENDBBUFFER_SIZE 32 
RING_TYPE sendbuffer[SENDBBUFFER_SIZE];
RINGPOS_TYPE ringw,ringr; /* ringbuffer positions for sending/receiving */
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
int main(void)
{
  unsigned char i,j,pos,state; // ledstat
  unsigned char need_confeeprom = 0; /* 1 = config to EEPROM requested */
  unsigned char kbdsend_delay = 0; /* give host some time to switch between send/receive modes (in config tool) */
  unsigned short kbdwait = 0;
  unsigned short rstwait = 0;
  unsigned short keyb_idle = 0;
  unsigned char inputstate; /* track inputs (Power,Floppy,CapsLock,extra inputs) */
  volatile unsigned char cur;
  unsigned char caps;
  unsigned char nrecv=0; /* commands from Host */
  unsigned char *recvcmd;

  /* disable clock prescaler: this is usually intended to be done by "make fuse" (see MakeFile),
     but when that step is omitted, the device would run at 2 MHz instead of 16 */
  CLKPR = 0x80; /* enable prescaler change */
#if (F_CPU == 8000000 )
  CLKPR = 0x01; /* prescaler 2 (0x1) 1 (0x0) */
#else
  CLKPR = 0x00;
#endif
//  clock_prescale_set(clock_div_2);



//  cli();

#ifdef ENABLE_WATCHDOG
  /* watchdog, clocking */
  MCUSR &= ~(1 << WDRF); /* Disable watchdog if enabled by bootloader/fuses */
//      wdt_disable();
  wdt_enable(WDTO_8S);    /* we hang for more than 8s -> reset */
#endif

  /* initialize computer communication ports (D2/D3 regular, F2/F3 in debug) */
  KBDSEND_SENDD &= ~(1<<KBDSEND_SENDB); /* send data port to input */
  KBDSEND_SENDP |=  (1<<KBDSEND_SENDB); /* def: high = pullup on   */
  KBDSEND_CLKD  &= ~(1<<KBDSEND_CLKB);  /* clock port to input     */
  KBDSEND_CLKP  |=  (1<<KBDSEND_CLKB);  /* def: high = pullup on   */ 

  /* initialize regular Caps LED */
  caps     = KEYIDLE; /* caps lock treated separately */
  LEDDDR  |=   1<<LEDPIN;       /* output */
  LEDPORT &= ~(1<<LEDPIN);	/* off */

  caps_on  = 1;         /* for LED controller */
  show_caps( caps_on ); /* light CAPS-lock until sync with Amiga */
//  ledstat  =  (1<<LEDPIN);	/* on  */
//  LEDPORT |=  (1<<LEDPIN);	/* on = NPN transistor switches to GND = LED on */

  /* initialized output ports (def: high) */
  ODDR    |= OMASK;     /* output */
  OPORT   |= OMASK;     /* high (i.e. no active scan in progress) */
//  OPORT   &= ~(OMASK);  /* low */

  /* initialize Input ports */
  for( i=0 ; kbinputlist[i] != 0 ; i++ )
  {
	*(&DDRD + kbinputports[i] ) &= ~(kbinputlist[i]); /* clear DDR bits -> input         */
	*(&PORTD+ kbinputports[i] ) |= (kbinputlist[i]); /* clear PORT bits -> enable pullup */
	//*(&PORTD+ kbinputports[i] ) &= ~(kbinputlist[i]); /* clear PORT bits -> no pullup  */
  }

  /* special keys (ALT,SHIFT,AMIGA,CTRL) */
  SPCDDR  &= ~(SPCMASK); /* input */
  SPCPORT |= SPCMASK;    /* pullup on */

  /* reset line available (A500) ? */
#ifdef KBDSEND_RSTP
  KBDSEND_RSTDDR &= ~(1<<KBDSEND_RSTB); /* input */
  RST_PORTIDLE	//  KBDSEND_RSTP   |=  (1<<KBDSEND_RSTB); /* pull-up RST */
#endif

  /* LED sources */
  DRVLED_DDR  &= ~(1<<DRVLED_BIT);
  DRVLED_PORT |=  (1<<DRVLED_BIT); /* in, with pull-up */

  IN3LED_DDR  &= ~(1<<IN3LED_BIT);
  IN3LED_PORT |=  (1<<IN3LED_BIT);
  IN4LED_DDR  &= ~(1<<IN4LED_BIT);
  IN4LED_PORT |=  (1<<IN4LED_BIT);

  PLED_DDR    &=  ~(1<<PLED_BIT);
  PLED_PORT   &=  ~(1<<PLED_BIT); /* we use this as analog input */
  ADCSRA = 0x87;                  /* Enable ADC, fr/128  */
  ADMUX  = 0x40;                  /* Vref: Avcc, ADC channel: 0 (PortF on AT90USB1287 */

  /* spare inputs (used for options) */
  KBD_SPARE1DDR  &= ~(1<<KBD_SPARE1B);
  KBD_SPARE1PORT |=  (1<<KBD_SPARE1B); /* in, with pull-up */
  KBD_SPARE2DDR  &= ~(1<<KBD_SPARE2B);
  KBD_SPARE2PORT |=  (1<<KBD_SPARE2B); /* in, with pull-up */

  /* init SPI pins (CLK,DAT) for extra LED chain (V4 Keyboards) */
  /* TODO: check KBD_SPARE2PIN & (1<<KBD_SPARE2B) for mounted resistor */
  LCD_SPI_Start(); /* spi.c */

  /* initialize keyboard states */
  for( i=0 ; i < OCOUNT*ICOUNT ; i++ )
  {
  	kbtable[i] = KEYIDLE;
  }

  /* init USB */
#ifdef ENABLE_USB
  usb_init();
#endif /* ENABLE_USB */

  /* init UART for serial communication to PC */
#ifdef DEBUG
  uart1_init(UART_BAUD_SELECT(9600UL,F_CPU));
  uart1_puts("AMIGA 500 KEYBOARD BY BAX\r\n");
#endif

  led_init(); /* start up LED controller (and enable interrupts) */
  TCCR2A = 0; /* normal mode, OC0A disconnected, OC0B disconnected,   */
#if (F_CPU == 8000000 )
  TCCR2B = (1<<CS22) | (1<<CS21); /* prescaler 256 -> 8 MHz/256 = 31250 Hz counter  -> 8 ms before overflow */
#else
  TCCR2B = (1<<CS20) | (1<<CS21) | (1<<CS22); /* prescaler 1024 -> 16 MHz/1024 = 15625 Hz counter -> 16.3 ms before overflow */
#endif
  TCNT2  = 0x00; /* start timer with 0 */
  TIFR2  = 0x01; /* clear TOV0 overflow flag (write 1 to set flag to 0) */
// while( (TIFR2 & 0x01) == 0  ) /* break waiting loop after 4ms */

//  sei(); /* needed for TWI, USB (and UART in debug mode) */

/*
  Gamma table
  track LED source changes -> send updated colors

  LED source map for LED 0-6
  LED color table idle/active
  LED mode regular/special (knight rider, rainbow, cycle)
*/

#if 0
  ADMUX  = (ADMUX&0xE0)|(0x00 & 0x7); /* select ADC channel 0 (channels 0-7 in lower 3 bits) */
  ADCSRA |= (1<<ADSC); /* start ADC (single conversion) */
  while((ADCSRA&(1<<ADIF))==0); /* wait for ADC */
  _delay_us(10);
  { uint8_t  AinLow;
    uint16_t Ain;
    AinLow = (int)ADCL;		/* lower 8 bit */
    Ain = ((uint16_t)ADCH)<<8;	/* upper two bit, shifted */
    Ain = Ain|AinLow;

    uart_puthexuint(Ain);
    DBGOUT(13);
    DBGOUT(10);
  }
#endif

  /* prime LED controller: all on, then all off */
  twi_wait();
  led_updatecontroller(0xff); /* update will only start if TWI is idle */
  inputstate = led_getinputstate();
  twi_wait();
  led_updatecontroller(inputstate);

  /* print HSV2RGB conversion */
#if 0
//#ifdef DEBUG
  if(1)
  {
	uint8_t rgb[3];

	DBGOUT(13);
	DBGOUT(10);
	for( i=0 ; i<255; i++ )
	{
		HSV2RGB( rgb, ((int16_t)i)<<2, 255,255 );
		uart_puthexuchar( rgb[0] );

	DBGOUT(32);
		uart_puthexuchar( rgb[1] );
	DBGOUT(32);
		uart_puthexuchar( rgb[2] );
	    DBGOUT(13);
	    DBGOUT(10);
	}
  }
#endif

#ifdef ENABLE_WATCHDOG
  /* start watchdog (for real, this time) */
  wdt_disable();
  wdt_enable(ENABLE_WATCHDOG);    /* we hang for more than 250ms -> reset */
#endif

  /* */
  init_ring();	/* prepare ringbuffer */
  state = STATE_POWERUP; /* synchronize with Amiga, perform power-up procedure */
  while( 1 ) 
  {
	inputstate = led_getinputstate(); /* get current inputs state */
	keyb_idle++;

#ifdef ENABLE_WATCHDOG
	wdt_reset();    /* we're alive (!) */
#endif

	/* Digital LED strip update -> make sure not to miss KB ACK */
	if( !(state & STATE_KBWAIT) )
	{
	 if( TIFR2 & 0x01 ) /* timer overflow (16.3ms) */
	 {
		TIFR2  = 0x01; /* clear TOV0 overflow flag (write 1 to set flag to 0) */
		led_digital_step();
	 }

#ifdef ENABLE_USB
		/* jump to USB main loop when USB connection was established */
		if( get_usb_config_status() != 0 )
		{
#ifdef DEBUG
  			uart1_puts("Entering USB mode\r\n");
#endif
			mainloop_usb();
#ifdef DEBUG
  			uart1_puts("Left USB mode\r\n");
#endif
			continue;
		}	
#endif /* ENABLE_USB */
	}

	while( state & (STATE_POWERUP|STATE_RESYNC) )
	{
		kbdwait = 0;
		/* synchronize with Amiga, stay here until Amiga answers */
#ifdef ENABLE_WATCHDOG
		wdt_reset();    /* we're alive (!), needed here because we're in a loop for potentially a long time */
#endif

		/* LED control is part of KBSync Mode */
//		led_updatecontroller(inputstate); /* */
#ifndef DEBUGONLY
		if( amiga_kbsync() > 0 )
#endif
			break;

#ifdef ENABLE_USB
		/* jump to USB main loop when USB connection was established */
		if( get_usb_config_status() != 0 )
		{
#ifdef DEBUG
	  		uart1_puts("Entering USB mode\r\n");
#endif
			mainloop_usb();
#ifdef DEBUG
  			uart1_puts("Left USB mode\r\n");
#endif
			continue;
		}	
#endif /* ENABLE_USB */
		/* CTRL-A-A while waiting for sync? */
		if( !(SPCPIN & ( (1<<SPCB_CTRL)+(1<<SPCB_LAMIGA)+(1<<SPCB_RAMIGA) ) ))
		{
#ifdef KBDSEND_RSTP
			KBDSEND_RSTDDR |=  (1<<KBDSEND_RSTB); /* output */
			KBDSEND_RSTP   &= ~(1<<KBDSEND_RSTB); /* /RST */
#endif
			KBDSEND_CLKD |=  (1<<KBDSEND_CLKB);  /* switch to output */
			KBDSEND_CLKP &= ~(1<<KBDSEND_CLKB);  /* clock low */
		}
		else
		{
			KBDSEND_CLKD  &= ~(1<<KBDSEND_CLKB);  /* switch to input */
			KBDSEND_CLKP  |=  (1<<KBDSEND_CLKB);  /* clock high (internal pullup) */
#ifdef KBDSEND_RSTP
			KBDSEND_RSTDDR &= ~(1<<KBDSEND_RSTB); /* input */
			RST_PORTIDLE  // KBDSEND_RSTP   |=  (1<<KBDSEND_RSTB); /* pull-up RST */
#endif
		}
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

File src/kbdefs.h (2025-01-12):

/*
  definitions for keyboard and Atmega ports

  requires prior loading of avr headers
*/
#ifndef KBDEFS_H
#define KBDEFS_H

/* LED port, pin as bit index */
#define LEDPORT PORTB
#define LEDDDR  DDRB
#define LEDPIN  7

/* OUTPUT PORT: MAX. 8 BITS */
#define OPORT  PORTA
#define ODDR   DDRA
#define OMASK  0xFC
/* output start bit, output stop bit */ 
#define OSTART (1<<2)
#define OMAX   (1<<7)

/* 6 outputs */
#define OCOUNT 6

/* input ports */
#define ICOUNT 15

/* computer communication port(s) */

#ifdef DEBUG
/* clock on PF2 in DEBUG MODE (IN_LED3) */
#define KBDSEND_CLKP PORTF
#define KBDSEND_CLKD DDRF
#define KBDSEND_CLKB 2
#define KBDSEND_CLKPIN PINF
/* kbdata out on PF3 in DEBUG MODE (IN_LED4) */
#define KBDSEND_SENDP PORTF
#define KBDSEND_SENDD DDRF
#define KBDSEND_SENDB 3
#define KBDSEND_PIN   PINF
#else /* DEBUG */
/* REGULAR */
/* clock on PD2 */
#define KBDSEND_CLKP PORTD
#define KBDSEND_CLKD DDRD
#define KBDSEND_CLKB 2
#define KBDSEND_CLKPIN PIND
/* kbdata out on PD3 */
#define KBDSEND_SENDP PORTD
#define KBDSEND_SENDD DDRD
#define KBDSEND_SENDB 3
#define KBDSEND_PIN  PIND
#endif 

/* special keys (ALT,SHIFT,AMIGA,CTRL) */
#define OCOUNT_SPC 1
#define SPCB_LAMIGA 6
#define SPCB_LALT   5
#define SPCB_LSHIFT 4
#define SPCB_CTRL   3
#define SPCB_RAMIGA 2
#define SPCB_RALT   1
#define SPCB_RSHIFT 0
#define SPCMASK  0x7F /* PB0-PB6 */
#define SPCPORT  PORTB
#define SPCDDR   DDRB
#define SPCPIN   PINB

#if 1
#define KBDSEND_ACKPIN KBDSEND_PIN
#define KBDSEND_ACKB   KBDSEND_SENDB
#else
/* kbd acknowledge input on PB0 (other keyboard) */
#define KBDSEND_ACKP PORTB
#define KBDSEND_ACKD DDRB
#define KBDSEND_ACKPIN PINB
#define KBDSEND_ACKB 0
#endif

/* kbd reset output on PB1 (A500) */
#define KBDSEND_RSTP   PORTD
#define KBDSEND_RSTDDR DDRD
#define KBDSEND_RSTPIN PIND
#define KBDSEND_RSTB 4

/* Reset pin handling: enable/disable pull-up */
#undef PULL_RST /* if pullup is disabled, then we can detect whether the keyboard 
                   is standalone or connected to an A500 */
#ifdef PULL_RST
#define RST_PORTIDLE   KBDSEND_RSTP   |=  (1<<KBDSEND_RSTB); /* pull-up RST */
#else
#define RST_PORTIDLE   KBDSEND_RSTP   &=  ~(1<<KBDSEND_RSTB); /* no pull-up on RST */
#endif

/* spare pads */
#define KBD_SPARE1PORT PORTD
#define KBD_SPARE1DDR  DDRD
#define KBD_SPARE1PIN  PIND
#define KBD_SPARE1B    6

#define KBD_SPARE2PORT PORTD
#define KBD_SPARE2DDR  DDRD
#define KBD_SPARE2PIN  PIND
#define KBD_SPARE2B    7



/* LED sources: Power (analog), Drive, LED3, LED4 */
#define PLED_DDR  DDRF
#define PLED_PORT PORTF
#define PLED_PIN  PINF
#define PLED_BIT 0
#define DRVLED_DDR  DDRF
#define DRVLED_PORT PORTF
#define DRVLED_PIN  PINF
#define DRVLED_BIT 1

/* IN_LED3, IN_LED4 are inactive in debug mode, just use a fake port in that case */
#ifndef DEBUG
#define IN3LED_DDR  DDRF
#define IN3LED_PIN  PINF
#define IN3LED_PORT PORTF
#define IN3LED_BIT 2

#define IN4LED_DDR  DDRF
#define IN4LED_PIN  PINF
#define IN4LED_PORT PORTF
#define IN4LED_BIT 3

#else /* DEBUG */
/* fake ports in debug mode: 4,5 are unused */
#define IN3LED_DDR  DDRF
#define IN3LED_PIN  PINF
#define IN3LED_PORT PORTF
#define IN3LED_BIT 4
#define IN4LED_DDR  DDRF
#define IN4LED_PIN  PINF
#define IN4LED_PORT PORTF
#define IN4LED_BIT 5
#endif /* DEBUG */


#endif /* KBDEFS_H */

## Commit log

2022-01-28 first upload
    [A500KB-B_Cu.gbl, A500KB-B_Mask.gbs, A500KB-B_Paste.gbp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]
2022-01-31 added Spacebar holder for extra springs, adjusted PCB
    [A500KB.kicad_pcb, Spacebar_ExtraSprings.skp, Spacebar_ExtraSprings.stl]
2022-02-01 Amiga software: fixed occasional hang
    [window.c]
2022-02-04 PCB update, Amiga software update - finished intended feature set for Amiga software: auto-load from keyboard, some status and error requesters, automatic custom screen if there are not enough availa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
    [A500KB.kicad_pcb, A500KB.sch]
2022-02-04 workaround for EEPROM issues
    [led.c]
2022-02-20 updates to led.c for keyboard ID
2022-02-23 fixed CLK signal in Sync mode
    [main.c]
2022-02-23 Amiga update (reduces warnings with GCC6.x) 3D printed parts for mounting in A3000/A4000 keyboard cases
    [A3000KB_Spacer_L.skp, A3000KB_Spacer_L.stl, A3000KB_Spacer_R.skp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]
2022-02-25 updated A2000-4000 reset logic (to immediate hard reset)
    [main.c]
2022-03-16 Some more adjustments to Footprints, updated doc
    [A500KB-B_Cu.gbl, A500KB-B_Fab.gbr, A500KB-B_Mask.gbs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]
2022-03-16 minor adjustments to main PCB
    [A500KB-B_Cu.gbl, A500KB-B_Fab.gbr, A500KB-B_Mask.gbs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]
2022-04-18 finalized V2 design, LED defaults include IN4 now
    [A500KB-B_Cu.gbl, A500KB-B_Fab.gbr, A500KB-B_Mask.gbs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]
2022-07-01 preparations for dynamic LED modes
2023-01-19 added additional LED cycling modes to ATMega firmware
2023-03-28 added A500KB Mini, Controller-only variant for Mitsumi Keyboards
    [A500KB-B_Cu.gbl, A500KB-B_Fab.gbr, A500KB-B_Mask.gbs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]
2023-08-02 Updated config program and Firmware - improved response when loading config from Keyboard - improved Reset handling of Keyboard
    [led.c, led.h, ledmanager.h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]
2023-09-05 added explicit clock prescaler change to ATMega program - previously, whenever the fuses were not programmed alongside the flash, the Keyboard would run at 2 MHz instead of the intended 16 MHz
2023-09-05 added note about Fuses to README
2023-09-06 PCB update - marked some unneeded components N/A - changed LED footprints to fit PLCC LEDs better - moved A500KBMini connector 0.5mm downwards
    [A500KB.kicad_pcb, A500KB.sch, A500KBMini.kicad_pcb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]
2023-10-03 reduced global LED power draw fixed Reset handling in unsynchronised state
    [led.c, main.c]
2023-12-20 added lha of Amiga Utility, updated Mini Gerbers
    [A500KB-B_Cu.gbl, A500KB-B_Fab.gbr, A500KB-B_Mask.gbs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]
2024-01-29 Add files via upload
    Added pictures of a build with Cherry Blue switches and vintage A2000 Cherry keycaps.
2024-02-05 LED frame and lens update
    [Keyboard_LEDs.skp, Keyboard_LEDs.stl, Keyboard_LEDs_Rahmen.stl]
2024-06-14 V0.3: improvements for CherryMX builds and fitment - plate design for CherryMX PCB mounted stabilizers (see PCB/A500KBPlate_Gerber_V2D.zip for Costar variant) - PCB modifications for better fitment i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
    [A3000KB_Spacer_VL.skp, A3000KB_Spacer_VL.stl, A3000KB_Spacer_VR.skp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]
2024-12-21 V4: optional LED strip on full PCB
    [A500KB.csv, A500KB.kicad_sch, A500KB.sch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]
2024-12-21 updated Gerbers
    [A500KB-B_Cu.gbl, A500KB-B_Fab.gbr, A500KB-B_Mask.gbs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]
2025-01-07 shifted A500KB connectors down on the PCB by 9mm This change allows angled connectors in conjunction with Dupont plugs for connection to the A500 mainboard.
    [A500KB-B_Cu.gbl, A500KB-B_Fab.gbr, A500KB-B_Mask.gbs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]
2025-01-07 plate update: 0.5mm more space for stabilizers
    [A500KBPlate.kicad_pcb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]
2025-01-08 V4c: fixed connector for A2k-A4k keyboard cables
    [A500KB-B_Cu.gbl, A500KB-B_Fab.gbr, A500KB-B_Mask.gbs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]
2025-01-12 Hardware finetuning, Amiga program update
    [A500KB-B_Cu.gbl, A500KB-B_Fab.gbr, A500KB-B_Mask.gbs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]
2025-01-13 moved connectors further left to improve clearance
    [A500KB-B_Cu.gbl, A500KB-B_Fab.gbr, A500KB-B_Mask.gbs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]
2025-01-14 small bugfix in power-up protocol handling
    [main.c]
2025-03-03 Updated Firmware and Amiga tool for BRG LEDs
    - SK9822 support (alongside APA102) for digital LEDs
    - added presets to Amiga program (A500 Red, A500 Green, Test mode)
2025-03-09 updated led_digital.c for RBG modes
2025-03-23 reduced digital LED power usage, added watchdog
2025-03-28 unified 3D printed parts for internal/external use
    [A3000KB_Spacer_L.skp, A3000KB_Spacer_L.stl, A3000KB_Spacer_R.skp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]
2025-03-28 PCB readme update
2025-03-31 added US-Only version (large Return, 2.75U LShift)
    [A500KB-B_Cu.gbl, A500KB-B_Fab.gbr, A500KB-B_Mask.gbs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]
2025-04-13 3D printed supports for Checkmate keyboard case
    [CheckMateKBCase_1.skp, CheckMateKBCase_BackHold.stl, CheckMateKBCase_Distknob.stl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]
2025-12-23 (optional) positioning adapter for CDTV keyboards
    [CDTVKeyboard_Stud_Adapter.skp, CDTVKeyboard_Stud_Adapter.stl]
2026-01-03 corrected LShift on US version plate gerbers
    [A500KBPlate.kicad_pcb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]

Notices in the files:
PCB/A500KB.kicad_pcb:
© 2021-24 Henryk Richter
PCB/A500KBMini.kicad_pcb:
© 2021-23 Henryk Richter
